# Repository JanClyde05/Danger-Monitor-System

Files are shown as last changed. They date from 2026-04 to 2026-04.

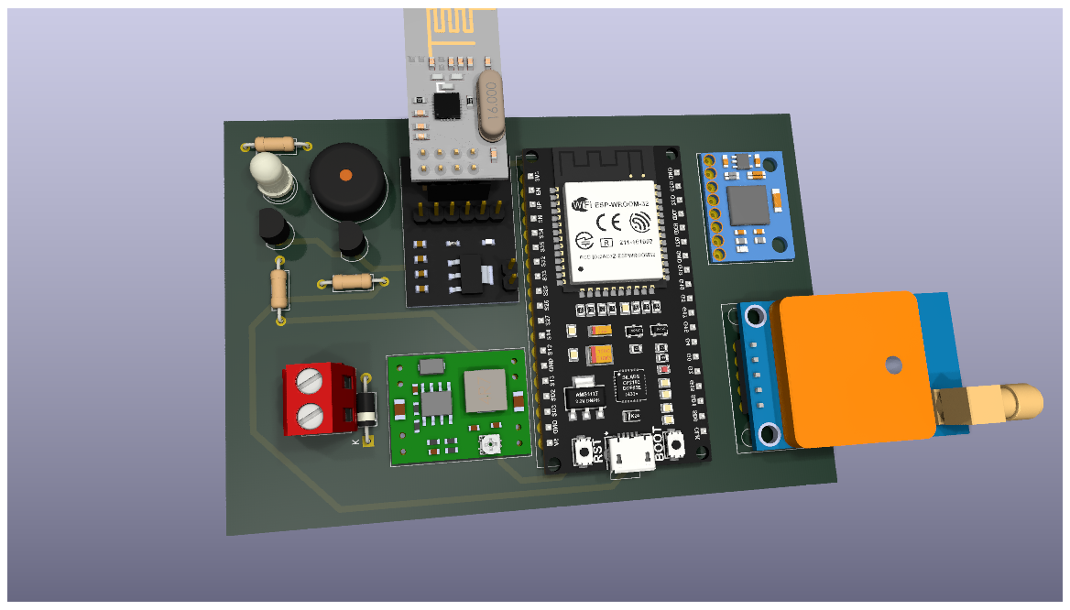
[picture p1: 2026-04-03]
images/Danger Monitor System 3D.png

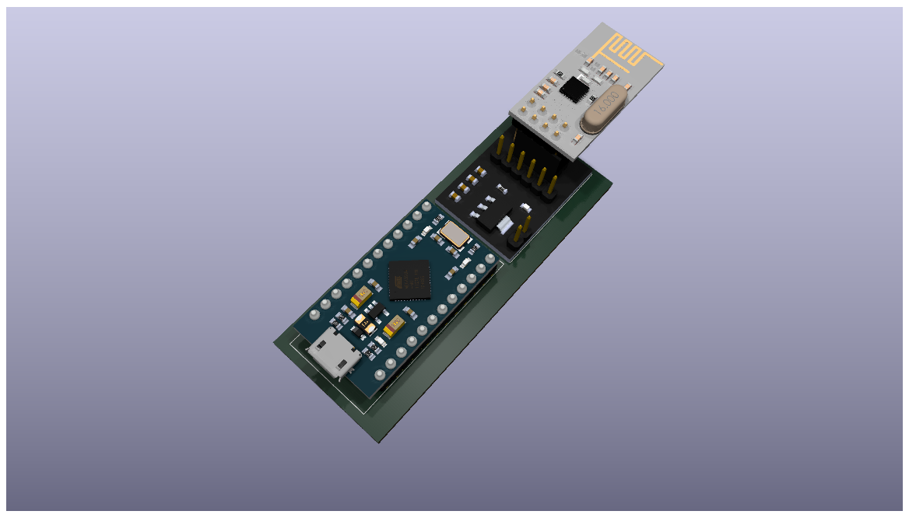
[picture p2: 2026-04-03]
images/Danger Monitor System_Receiver 3D.png

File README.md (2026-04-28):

# GPS Danger Monitor System – Full Code Documentation (v4.1)
##### BY: JAN CLYDE T. TALOSIG
##### **NEW IN v4.1: Physical Button Two-State Toggle + GPS Share / Open in Maps**
##### **NEW IN v4.0: Physical Disarm Button + False Alarm NRF Broadcast**
##### **NEW IN v3.x / Web Portal: Confirmed Accident Database + Diagnosis Notes + SOS Audio**

---

# 1. SYSTEM OVERVIEW

## 1.1 Purpose

The system is a **wearable/embedded safety monitor** that detects:

* Human falls (high confidence – three-stage FSM)
* Skid / slide events (lateral acceleration + roll rate)
* Direct high-G impacts (no freefall precondition)
* Environmental hazards (ground shock / structural instability / wave motion)

It then:

1. Gets GPS coordinates (last-known-location strategy)
2. Sends them via NRF24L01 with a token-prefixed payload
3. Triggers an SOS alert (LED + buzzer, Morse SOS pattern)
4. Opens a **web-based emergency profile with QR code quick-dial** via HID receiver
5. Allows the user to **cancel a false alarm** via physical button or web dashboard, which broadcasts a `FA,TOKEN,LAT,LNG` NRF packet to notify the receiver

---

## 1.2 System Components

### Transmitter (ESP32) – v4.1

* Sensors:
  * MPU-6050 (motion / orientation)
  * GPS module via TinyGPS++ (UART1, RX=16, TX=17)
* Communication:
  * NRF24L01 (wireless, CE=2, CSN=15)
* Interface:
  * Web dashboard in AP mode (three tabs: Monitor, Diagnostics, Simulation)
  * Physical disarm/re-arm button on GPIO 0 (BOOT button)

### Receiver (Pro Micro) – v2.3

* NRF24L01 (receiver, CE=9, CSN=10)
* HID Keyboard emulation (opens Netlify URL in browser)
* Handles three payload types: EMERGENCY, TEST, FALSE ALARM

### Web Layer

* ESP32 embedded dashboard (AP mode, 192.168.4.1)
* Netlify emergency portal (multi-page SPA with router)

---

# 2. ABSTRACT PROGRAM FLOW (SUMMARY)

## HIGH-LEVEL FLOW

```
BOOT → INIT HARDWARE → CALIBRATION → RUN LOOP
         ↓
     READ SENSORS (IMU + GPS)
         ↓
    APPLY SIM OVERRIDE (if drill mode)
         ↓
  UPDATE FALL-IMPACT-STILLNESS FSM
         ↓
  CHECK SKID / DIRECT IMPACT DETECTORS
         ↓
  CHECK ENVIRONMENTAL ANALYSIS (every 1 s)
         ↓
  SEND NRF ALERT + SOS (if triggered)
         ↓
  POLL PHYSICAL BUTTON (two-state toggle)
         ↓
  UPDATE WEB UI + BURST TEST (non-blocking)
         ↓
       REPEAT
```

---

## CORE LOGIC PIPELINES

### FALL DETECTION PIPELINE

```
[FS_IDLE]
   ↓ A_m < 0.40 g
[FS_FREEFALL]
   ↓ sustained ≥ 100 ms
[FS_WAIT_IMPACT]
   ↓ A_m > 3.00 g within 500 ms
[FS_STILLNESS]
   ↓ σ(A_m) < 0.15 g over 2 s
[FS_CONFIRMED → ALERT]
```

All stages must pass — eliminates false positives from jumping, device drops, or sleeping.

---

### SECONDARY DETECTORS (Parallel to FSM)

```
SKID / SLIDE:
  ay > 2.0 g  AND  gx > 330 °/s  sustained ≥ 200 ms
  → Ref: motorcycle crash paper, 96% accuracy

DIRECT IMPACT:
  A_m spike > 4.50 g  (no freefall precondition)
  5 s debounce between events
  → Ref: construction-site LF falls 4–9 g (Sensors 2022)
```

---

### EMERGENCY RESPONSE PIPELINE

```
[ACCIDENT DETECTED]
   ↓
[NRF PAYLOAD: "TOKEN,LAT,LNG"]
   ↓
[RECEIVER HID TRIGGERS URL]
   ↓
[NETLIFY PROFILE PAGE OPENS]
   ↓
[MEDICAL INFO + QR CODE DISPLAYED]
   ↓
[RESPONDER SCANS QR → tel: DIALS CONTACT]
   ↓ (optional)
[RESPONDER CONFIRMS ACCIDENT → DATABASE ENTRY]
```

---

### FALSE ALARM CANCELLATION PIPELINE (v4.0+)

```
[ALERT ACTIVE]
   ↓ (user presses physical button OR web False Alarm button)
[stopSOSAlert() — LED/buzzer off]
   ↓
[nrfSendFalseAlarm(): "FA,TOKEN,LAT,LNG"]
   ↓
[RECEIVER HID TRIGGERS FALSE ALARM URL]
   ↓
[NETLIFY: green "USER IS SAFE" page]
   ↓
[RESCUER INFORMED — NO RESPONSE NEEDED]
```

---

# 3. DETAILED MODULE EXPLANATION

## 3.1 SETUP PHASE

```
setup():
  Start Serial (115200)
  Start GPS UART1 (9600 baud, RX=16, TX=17)
  Initialize I2C (Wire.begin)
  Wake MPU-6050 (write 0x00 to PWR_MGMT_1)
  Calibrate MPU (3 seconds, 200 samples)
  Record gpsSearchStart timestamp
  Start WiFi AP (SSID: "GPS Danger Monitor", open, IP: 192.168.4.1)
  Initialize NRF24 (CE=2, CSN=15, PA_HIGH, 32-byte payload)
  Register all WebServer routes
  Configure GPIO: LED (4), Buzzer (5), Button (0 INPUT_PULLUP)
```

---

## 3.2 MAIN LOOP STRUCTURE

```
loop():
  Compute delta time dt
  server.handleClient()
  Poll physical button (50 ms debounce, two-state toggle)
  Run NRF burst test step (non-blocking, if pending)
  Feed GPS bytes → TinyGPS++, update hasFix / lastLat / lastLng
  readMPU() → apply sim override → updateOrientation(dt)
  Compute A_m = sqrt(ax²+ay²+az²)
  pushEnvSample(A_m, roll, pitch)
  Run Fall-Impact-Stillness FSM (if armed)
  Run Skid detector (if armed, FSM idle)
  Run Direct-Impact detector (if armed, FSM idle, not in skid)
  Environmental analysis (every 1 s, if armed, not sim)
  Drive SOS pattern (non-blocking)
```

---

# 4. SENSOR PROCESSING

## 4.1 MPU DATA FLOW

```
Raw MPU Data → Bias Removal → Physical Units → Orientation Estimation
```

### readMPU()

* Reads 14 bytes from register 0x3B
* Extracts ax, ay, az (±2 g range → /16384) and gx, gy, gz (±250 °/s → /131)
* Subtracts calibration offsets

### calibrateMPU()

* 200 samples over CALIB_MS (3000 ms)
* Averages each axis; subtracts 1.0 g from az bias (gravity)
* Stores: aBiasX/Y/Z, gBiasX/Y/Z

### updateOrientation(dt)

Complementary filter (α = 0.02):

```
aRoll  = atan2(ay, az) × 57.296°
aPitch = atan2(-ax, √(ay²+az²)) × 57.296°

roll  = (1-α)×(roll  + gx×dt) + α×aRoll
pitch = (1-α)×(pitch + gy×dt) + α×aPitch
```

## 4.2 ACCELERATION MAGNITUDE

```
A_m = sqrt(ax² + ay² + az²)
```

Orientation-independent scalar used by all detection stages.

---

# 5. FALL DETECTION STATE MACHINE

## States

| State | Meaning |
|---|---|
| FS_IDLE | Normal monitoring |
| FS_FREEFALL | Low-gravity condition detected |
| FS_WAIT_IMPACT  | Waiting for impact spike |
| FS_STILLNESS | Verifying post-impact unconscious |
| FS_CONFIRMED | Alert triggered |

## Full Flowchart

```
FS_IDLE
  IF A_m < 0.40 g → FS_FREEFALL, start timer

FS_FREEFALL
  IF A_m ≥ 0.40 g → back to FS_IDLE (false trigger)
  IF duration ≥ 100 ms → FS_WAIT_IMPACT
    Record fallStartMs, increment fallEventCount

FS_WAIT_IMPACT
  IF A_m > 3.00 g → FS_STILLNESS, reset stillness buffer
  IF timeout > 500 ms → FS_IDLE, increment fallCancelCount

FS_STILLNESS
  Collect samples for 2000 ms
  Compute σ(A_m)
  IF σ < 0.15 g → FS_CONFIRMED
  ELSE          → FS_IDLE (user conscious), increment fallCancelCount

FS_CONFIRMED
  Increment fallConfirmCount
  Log response time (now − fallStartMs)
  IF !simMode → nrfSendCoords(lastLat, lastLng, "Fall confirmed")
  ELSE        → nrfSendTest(99, "SIMFALL")
  startSOSAlert()
  → FS_IDLE
```

## Why This Works (Thesis Logic)

* Freefall alone → jumping false positive
* Impact alone → dropping the device
* Stillness alone → user sleeping
* **Combination of all three = confirmed real accident**

---

# 6. SECONDARY DETECTORS

## 6.1 Skid / Slide Detector

Active when: `armed == true` AND `fallState == FS_IDLE`

```
Condition: fabsf(ay) > 2.0 g  AND  fabsf(gx) > 330 °/s

If condition holds:
  Start skid timer on first detection
  If sustained ≥ 200 ms:
    skidCount++
    nrfSendCoords() OR nrfSendTest (sim)
    startSOSAlert()
    inSkid = false (reset)

If condition breaks before 200 ms:
  inSkid = false (cancel)
```

Reference: motorcycle crash paper, lateral 0.70 g + roll rate criteria, 96% accuracy.
*(Note: firmware thresholds are set higher — 2.0 g / 330 °/s — for reduced false positives in the specific deployment scenario.)*

---

## 6.2 Direct Impact Detector

Active when: `armed == true` AND `fallState == FS_IDLE` AND `!inSkid`

```
Condition: A_m > 4.50 g  AND  (now − lastImpactAlert) > 5000 ms

  lastImpactAlert = now
  impactCount++
  nrfSendCoords() OR nrfSendTest (sim)
  startSOSAlert()
```

Reference: Sensors 2022 — low-floor fall studies, 4–9 g impact range.

---

## 6.3 Environmental / Structural Instability

Runs every 1000 ms using the last `bufCount` samples from the rolling buffer (max 50).

```
sMag   = stddev(magBuf)
sRoll  = stddev(rollBuf)
sPitch = stddev(pitchBuf)

groundShock:  sMag ≥ 0.40  AND  sRoll < 10.0  AND  sPitch < 10.0
waveMotion:   sMag ≥ 0.24  AND  (sRoll ≥ 10.0 OR sPitch ≥ 10.0)

IF groundShock → nrfSendCoords("Ground shock")   + startSOSAlert()
IF waveMotion  → nrfSendCoords("Wave motion")     + startSOSAlert()
```

*(Environmental analysis is suppressed during simulation mode.)*

---

# 7. PHYSICAL BUTTON – TWO-STATE TOGGLE (v4.1)

**Pin:** GPIO 0 (BOOT button). Active-low with INPUT_PULLUP. 50 ms debounce on falling edge.

```
State A — alertActive = true:
  Press → armed = false
         stopSOSAlert()
         nrfSendFalseAlarm()   ← broadcasts "FA,TOKEN,LAT,LNG"
         lastEvent = "PHYSICAL DISARM – false alarm NRF sent/failed"

State B — armed = false (device was disarmed):
  Press → armed = true
         fallState = FS_IDLE
         inSkid = false
         lastEvent = "Re-armed via physical button"

Ignored — armed = true, alertActive = false:
  (Nothing to cancel — press is silently ignored)
```

---

# 8. NRF COMMUNICATION

## 8.1 Payload Formats (v4.1)

| Type | Format | Example |
|---|---|---|
| EMERGENCY | `TOKEN,LAT,LNG` | `DM-001,14.599512,120.984222` |
| FALSE ALARM | `FA,TOKEN,LAT,LNG` | `FA,DM-001,14.5995,120.9842` |
| TEST (burst/sim)| `TEST,NN,<tag>` | `TEST,01,SIMFALL` |

All payloads are 32 bytes (NRF_PAYLOAD). Lat/Lng precision is 6 decimal places for EMERGENCY, 4 decimal places for FALSE ALARM (to fit within the 32-byte limit alongside the `FA,` prefix and token).

**Known hardware constraint:** IMU readings (ax, ay, gx) are NOT included in the FALSE ALARM payload. The 32-byte capacity is fully occupied by token + GPS coordinates. The Netlify portal displays "—" for IMU fields on the false alarm page and explicitly notes this constraint.

---

## 8.2 NRF Send Functions

### nrfSendCoords(lat, lng, reason)
* Formats `TOKEN,LAT,LNG` into a 32-byte buffer
* Calls `radio.write()`
* Updates `lastEvent`

### nrfSendFalseAlarm()
* Formats `FA,TOKEN,LAT,LNG` (4-decimal precision)
* Calls `radio.write()`
* Returns bool success

### nrfSendTest(seq, tag)
* Formats `TEST,NN,<tag>` (used by burst test and simulation drills)
* Prevents real emergency alerts during drill mode

---

## 8.3 NRF Hardware Config

| Parameter | Value |
|---|---|
| CE Pin | GPIO 2 |
| CSN Pin | GPIO 15 |
| MOSI/MISO/SCK| 23 / 19 / 18 |
| Address | 0xE8E8F0F01LL |
| Payload size | 32 bytes |
| PA Level | RF24_PA_HIGH |
| Mode | TX (transmitter only)  |

---

# 9. WEB SERVER + DASHBOARD (ESP32)

## 9.1 Endpoints

| Route | Function |
|---|---|
| `/` | Serves full dashboard HTML (three tabs) |
| `/status.json` | Live sensor data (armed, alertActive, GPS, IMU, fall state, sim) |
| `/diag-stats.json` | GPS fix stats, fall event counters, burst state |
| `/burst-results.json`  | 20-shot burst test results per packet |
| `/arm` | Set armed = true |
| `/disarm` | Set armed = false, stop SOS; if alertActive → send FA NRF |
| `/false-alarm` | Manual FA: only works when alertActive; sends FA NRF  |
| `/test-nrf` | Single legacy NRF test packet |
| `/run-burst` | Start 20-packet burst test (non-blocking) |
| `/simulate?event=X` | Start simulation (skid / fall / impact) |
| `/sim-stop` | Stop simulation, reset IMU to idle state |

## 9.2 /status.json Fields

```json
{
  "armed":       true,
  "alertActive": false,
  "hasFix":      true,
  "lat":         14.599512,
  "lng":         120.984222,
  "roll":        2.30,
  "pitch":      -1.20,
  "aMag":        1.023,
  "ay":          0.012,
  "gx":          0.5,
  "nrfReady":    true,
  "fallState":   0,
  "simEvent":    0,
  "inSkid":      false,
  "lastEvent":   "System boot"
}
```

## 9.3 Dashboard Tabs

### Monitor Tab
* **Alert Active Banner** — animated red banner shown when `alertActive = true`; includes hint about physical button and False Alarm button
* **System Controls** — Arm, Disarm, False Alarm (disabled when no active alert), NRF Single Test
* **Live Sensor Data** — 11 KV tiles: Armed, Alert Active, GPS Fix, Lat, Lng, Roll, Pitch, |A|, A-Y lateral, GX roll rate, NRF24 status
* **Fall Pipeline Bar** — color-coded progress bar across 5 FSM stages
* **GPS Location Actions** (v4.1 new):
  * **Share Location** button — copies `https://www.google.com/maps?q=LAT,LNG` to clipboard; disabled until valid GPS fix
  * **Open in Maps** button — opens Google Maps pin in new browser tab; disabled until valid GPS fix
  * GPS coordinate display below buttons (green when fix acquired)
* **Last Event** — monospace event log display
* **Detection Thresholds Reference** — literature-backed threshold summary with physical button behavior note

### Diagnostics Tab
* **NRF Burst Test** — 20-shot burst with per-packet ACK/FAIL status, latency bar, summary stats (success rate, avg/min/max delay)
* **GPS Fix Statistics** — fix count, average time-to-fix, current fix status
* **Fall Detection Diagnostics** — events detected, confirmed alerts, cancelled events, avg response time, precision rate, skid count, direct impact count

### Simulation Tab
* **Event Buttons** — Simulate Skid (SIM_SKID), Simulate Fall (SIM_FALL), Simulate Impact (SIM_IMPACT), Stop Sim
* **Sim Status Display** — live status string from `lastEvent`
* **IMU Threshold Reference Table** — literature-backed thresholds with event name, value, condition, and source
* **Live IMU Waveform Canvas** — rolling 80-sample aMag plot with threshold lines (freefall 0.40 g, skid 0.70 g, impact 3.00 g, direct 4.00 g)

---

# 10. IMU SIMULATION MODE

Three simulation events inject synthetic IMU waveforms to test the detection pipeline end-to-end without physically triggering the device.

### SIM_SKID (~700 ms)
* Sine-enveloped lateral ay peak ~0.85 g + gx peak ~55 °/s
* Designed to cross SKID_LATERAL_G and SKID_ROLL_RATE thresholds
* Sends `nrfSendTest(98, "SIMSKID")` instead of real alert

### SIM_FALL (~2650 ms)
```
0–100 ms  : Pre-fall lean (az drops, gx rises)
100–280 ms: Freefall (A_m ≈ 0.18 g — well below 0.40 g threshold)
280–330 ms: Impact spike (A_m ≈ 4.8 g — above 3.00 g threshold)
330–2650 ms: Stillness (σ < 0.05 g — below 0.15 g threshold)
```
* Sends `nrfSendTest(99, "SIMFALL")`

### SIM_IMPACT (~200 ms)
* Gaussian impulse: peak A_m ≈ 4.8 g (above IMPACT_DIRECT_G = 4.50 g)
* Sends `nrfSendTest(97, "SIMIMPACT")`

All simulations set `lastEvent` with drill status and suppress real NRF emergency packets.

---

# 11. RECEIVER (PRO MICRO) – v2.3

## 11.1 Three Payload Types

```
WAIT for NRF packet (radio.available())
   ↓
Read 32-byte payload → String raw
   ↓
Detect type:
  raw.startsWith("TEST,")  → TEST handler
  raw.startsWith("FA,")    → FALSE ALARM handler
  else                     → EMERGENCY handler
```

## 11.2 EMERGENCY Handler

```
Parse: TOKEN = raw[0..c1], COORDS = raw[c1+1..]
Build URL: https://danger-monitor-profile.netlify.app/?token=TOKEN&loc=LAT,LNG
Debounce: 1500 ms between triggers
openURL(url) → HID keyboard simulation
```

## 11.3 FALSE ALARM Handler (v2.3 New)

```
Parse: FA | TOKEN | LAT | LNG
Build URL: https://danger-monitor-profile.netlify.app/?falarm=1&token=TOKEN&loc=LAT,LNG
Debounce: 1500 ms
openURL(url) → HID keyboard simulation
```
→ Netlify displays **green "USER IS SAFE" page** instead of emergency profile.

## 11.4 TEST Handler

```
Parse seq number from "TEST,NN,tag"
Build URL: https://danger-monitor-profile.netlify.app/?nrftest=1&seq=NN&ts=millis
Debounce: 1500 ms
openURL(url)
```
→ Netlify shows a toast notification and stays on home page.

## 11.5 openURL() – HID Sequence

```
Keyboard.press(Ctrl + L)   → focus address bar
Keyboard.releaseAll()
delay(250)
Keyboard.press(Ctrl + A)   → select existing URL
Keyboard.releaseAll()
delay(80)
Keyboard.print(url)        → type new URL
delay(80)
Keyboard.write(KEY_RETURN) → navigate
```

## 11.6 Wiring

| NRF24 Pin | Pro Micro Pin |
|---|---|
| CE | 9 |
| CSN | 10 |
| MOSI | 16 (MOSI) |
| MISO | 14 (MISO) |
| SCK | 15 (SCK) |
| VCC | 3.3 V only |

---

# 12. NETLIFY EMERGENCY PORTAL (Web Layer)

## 12.1 Technology Stack

```
HTML5 / CSS3 / Vanilla JavaScript
QRCode.js (CDN: cdnjs.cloudflare.com)
localStorage (Confirmed Accident Database)
Web Audio API (SOS sound engine)
No backend required — fully static
```

## 12.2 URL Router

The portal reads URL parameters on load and routes to the correct page:

| URL Pattern | Page Shown |
|---|---|
| `/` (no params) | Home – Device Grid |
| `/?token=DM-001&loc=14.599,120.984` | Emergency Profile |
| `/?falarm=1&token=DM-001&loc=14.5995,120.9842` | False Alarm – Safe Page |
| `/?nrftest=1&seq=NN&ts=...` | Home + toast |
| `/?loc=14.599,120.984` (no token) | First profile (legacy)  |
| `/?token=DM-XXX` (unknown token) | Token Not Found page |

## 12.3 Pages

### Home Page
* Hero section: system description, stats (device count, repeater spacing, RF protocol)
* **Device Grid** — card per profile showing avatar, name, role, token, blood type, contact
* Clicking any card opens that profile's Emergency Profile view

### Emergency Profile Page
* **Alert Banner** — animated red pulsing banner with SOS mute toggle button
* **Audio Unlock Bar** — shown on mobile when autoplay is blocked; tap to enable SOS alarm
* **Medical Profile Card** — avatar, name, role, token, blood type, allergies, emergency contact, medical notes
* **QR Code Section** — auto-generated `tel:` QR code for instant emergency contact dial
* **Location Card** — live coordinates, Google Maps button (hidden if no location)
* **Rescuer Action Row**:
  * **Share Alert** — copies current emergency URL to clipboard
  * **Confirm Accident** — opens token-confirmation modal; logs entry to Confirmed Accident Database
* Back button → Home

### False Alarm Page
* **Safe Banner** — green pulsing "USER IS SAFE" banner
* **Safe Status Row** — green indicator dot + "DEVICE OWNER CONFIRMED SAFE" text
* **Profile Card (green border)** — same medical info as emergency profile
* **IMU Readings at Disarm** — displays "—" for all three fields with hardware constraint note
* **Location Card** — last-known GPS position

### Confirmed Accident Database Page
* Header with record count and Clear All button
* Per-entry cards showing: avatar, name, token, confirmed timestamp, coordinates (Maps link), medical summary
* **Medical Diagnosis Notes** — collapsible section per accident:
  * Add Text Note (textarea)
  * Add Image (file input → base64)
  * Attach File (file input → base64 data URL)
  * Delete individual notes
* **Delete Accident Record** — per-card ✕ button; requires token confirmation via modal
* Empty state placeholder when no records

### Token Not Found Page
* Shows the unrecognized token string
* Back button → Home

## 12.4 Token Confirmation Modal

Used for both "Confirm Accident" and "Delete Record" actions.

```
openModal({
  mode:  'confirm' | 'delete',
  token: required token string,
  onOk:  callback on success
})
```

* User must type the device token exactly (case-insensitive) to unlock the OK button
* Input highlights green on match; button label differs by mode ("Log to Database" vs "Delete")
* Dismiss via Cancel button, backdrop click, or Escape key

## 12.5 QR Code System

```javascript
generateQRCode(phoneNumber, containerId)
  telLink = 'tel:' + phoneNumber.replace(/\s/g, '')
  new QRCode(container, {
    text:         telLink,
    width:        200, height: 200,
    colorDark:    '#000000',
    colorLight:   '#ffffff',
    correctLevel: QRCode.CorrectLevel.H   // 30% error recovery
  })
```

| Property | Value |
|---|---|
| Encoding | `tel:` URI protocol |
| Size | 200 × 200 px |
| Error Correction| Level H (30% recovery) |
| Generation | Client-side (instant)  |
| Offline support | Yes (no network needed)|

## 12.6 SOS Audio Engine

Non-blocking Morse SOS pattern using Web Audio API:

```
Pattern: ... --- ...  (dot=80ms, dash=240ms, gap=80ms, long gap=240ms, word gap=560ms)
Tone:    880 Hz sine wave, gain 0.35
```

* `SOS.tryAutoplay()` — called on profile load; shows unlock bar if browser blocks autoplay
* `SOS.start()` / `SOS.stop()` — start/stop the oscillator pattern loop
* `SOS.toggleMute()` — mute/unmute without stopping the pattern timer
* SOS is always stopped when navigating to False Alarm page or Home

## 12.7 Confirmed Accident Database (localStorage)

```
Key: 'dm_accidents'
Schema per entry:
{
  id:          string (timestamp),
  confirmedAt: ISO date string,
  token:       "DM-XXX",
  profile:     { ...snapshot of profile at time of confirmation },
  loc:         "LAT,LNG" or "",
  url:         full emergency URL,
  diagNotes:   [
    {
      id:       string,
      addedAt:  ISO date string,
      type:     "text" | "image" | "file",
      content:  text string | base64 data URL,
      fileName: string,
      mimeType: string
    }
  ]
}
```

Entries are stored newest-first. Image and file notes are stored as base64 data URLs. A 2 MB per-file warning prompt is shown to prevent exceeding localStorage limits (~5–10 MB per origin).

## 12.8 Registered Profiles

```javascript
const PROFILES = [
  { token: "DM-001", name: "Jan Clyde Talosig",     blood: "B+",  allergies: "None",          ... },
  { token: "DM-002", name: "James Laurence Guzman", blood: "O+",  allergies: "Skin Allergies", ... },
  { token: "DM-003", name: "Kaye Angelique Aquino", blood: "A+",  allergies: "None",           ... },
  { token: "DM-004", name: "Shamel Alliyah Senson", blood: "AB+", allergies: "None",           ... },
  { token: "DM-005", name: "Zarina Marie Aguilar",  blood: "AB+", allergies: "None",
    notes: "Have history of heart complications"                                                  },
];
```

To add a new device, append a new object to the `PROFILES` array in `emergency_portal_qr.html`.

---

# 13. SOS ALERT SYSTEM

## Pattern

Morse Code SOS: `... --- ...` (non-blocking)

```javascript
const SOS_STEPS = [
  {on:true,ms:150},{on:false,ms:150},  // S dot 1
  {on:true,ms:150},{on:false,ms:150},  // S dot 2
  {on:true,ms:150},{on:false,ms:150},  // S dot 3
  {on:true,ms:450},{on:false,ms:150},  // O dash 1
  {on:true,ms:450},{on:false,ms:150},  // O dash 2
  {on:true,ms:450},{on:false,ms:150},  // O dash 3
  {on:true,ms:150},{on:false,ms:150},  // S dot 1
  {on:true,ms:150},{on:false,ms:150},  // S dot 2
  {on:true,ms:150},{on:false,ms:600},  // S dot 3 + word gap
];
```

* LED (GPIO 4) and Buzzer (GPIO 5, 3000 Hz) toggled in sync
* `startSOSAlert()` — sets `alertActive = true`, starts pattern
* `stopSOSAlert()` — sets `alertActive = false`, turns off LED and buzzer
* Pattern cycles with `millis()` timing — does not block the main loop

---

# 14. GPS HANDLING

## Strategy: Last-Known Location

```
IF GPS valid:
    update lastLat, lastLng
    IF first fix after search: record fix time, increment gpsFixCount
ELSE:
    keep last valid coordinates (lastLat, lastLng)

IF fix age > 8000 ms:
    hasFix = false → start searching
```

## GPS Diagnostics

Tracked in firmware and exposed via `/diag-stats.json`:
* `gpsFixCount` — number of times a fix was (re-)acquired
* `gpsTotalFixMs` — cumulative time-to-fix; divide by count for average
* `gpsSearchStart` — timestamp of last fix-lost event

---

# 15. SYSTEM STATES

## Armed Mode (`armed = true`)

* All detection FSMs active (fall, skid, direct impact, environmental)
* SOS alerts allowed
* NRF broadcasting enabled
* Physical button in State A/Ignored logic

## Disarmed Mode (`armed = false`)

* All FSMs reset to idle
* SOS stopped
* NRF dormant
* Physical button in State B (re-arm) logic

## Alert Active (`alertActive = true`)

* Subset of armed mode — a confirmed event is in progress
* SOS LED/buzzer cycling
* Web dashboard shows animated red banner
* False Alarm button enabled
* Physical button triggers disarm + FA NRF

---

# 16. KEY VARIABLES YOU CAN MODIFY

## Detection Thresholds

```cpp
// Fall-Impact-Stillness
FREEFALL_G        = 0.40f    // g — below this triggers freefall
IMPACT_G          = 3.00f    // g — above this after freefall = impact
STILLNESS_STD_MAX = 0.15f    // g σ — below this = unconscious
FREEFALL_DUR_MS   = 100      // ms — min freefall duration
IMPACT_WINDOW_MS  = 500      // ms — impact must occur within this window
STILLNESS_DUR_MS  = 2000     // ms — stillness observation window

// Skid
SKID_LATERAL_G    = 2.0f     // g — lateral ay threshold
SKID_ROLL_RATE    = 330.0f   // °/s — gx roll rate threshold
SKID_DUR_MS       = 200      // ms — sustained duration

// Direct Impact
IMPACT_DIRECT_G   = 4.50f    // g — spike threshold
IMPACT_DEBOUNCE   = 5000     // ms — minimum time between direct impact alerts

// Environmental
ACC_STD_DANGER    = 0.40f    // g σ — acceleration variance threshold
ROLL_PITCH_STD    = 10.0f    // ° σ — orientation variance threshold
ANALYZE_EVERY_MS  = 1000     // ms — analysis interval
```

## Hardware Pins

```cpp
GPS_RX = 16, GPS_TX = 17, GPS_BAUD = 9600
MPU_ADDR = 0x68 (I2C, SDA=21, SCL=22)
NRF_CE = 2, NRF_CSN = 15
ALERT_LED_PIN = 4
BUZZER_PIN = 5
DISARM_BTN_PIN = 0
```

## Device Token

```cpp
const char* DEVICE_TOKEN = "DM-001";
```

Each physical device must have a unique token matching an entry in the `PROFILES` array.

---

# 17. FULL SYSTEM ARCHITECTURE

## v4.1 Block Diagram

```
[MPU6050] ──┐
            ├─→ ESP32 ─→ FALL / SKID / IMPACT FSMs ─→ NRF24 ──┐
[GPS]    ───┘      ↓              ↓                            │
                SOS ALERT   Physical BTN (GPIO 0)              │
               (LED/Buzz)    ↓ (if alertActive)                │
                         FA NRF packet ──────────────────────  │
                                                               ↓
                                                          Pro Micro
                                                               ↓
                                                 HID Keyboard Emulation
                                                               ↓
                                              Browser → Netlify Portal
                                                               ↓
                                         ┌──────────────────────────────┐
                                         │  Emergency Profile + QR      │
                                         │  OR False Alarm Safe Page    │
                                         │  OR Test Toast Notification  │
                                         └──────────────────────────────┘
                                                               ↓
                                                  Responder Scans QR
                                                               ↓
                                                   Phone Auto-Dials
                                                               ↓
                                           (optional) Confirm Accident
                                                               ↓
                                              Accident Database Entry
                                                               ↓
                                          Medical Personnel Adds Notes
```

---

## Data Flow – Emergency Scenario

```
TRANSMITTER (ESP32):
  Fall / Skid / Impact Detected
       ↓
  GPS: lastLat, lastLng
       ↓
  Payload: "DM-001,14.599512,120.984222"
       ↓
  NRF24 → radio.write()
       ↓
  SOS LED + Buzzer activated

RECEIVER (Pro Micro):
  radio.available() → radio.read()
       ↓
  Payload type: EMERGENCY (no "FA," prefix, no "TEST," prefix)
       ↓
  Parse: token="DM-001", coords="14.599512,120.984222"
       ↓
  URL: https://danger-monitor-profile.netlify.app/?token=DM-001&loc=14.599512,120.984222
       ↓
  HID: Ctrl+L → Ctrl+A → type URL → Enter

NETLIFY PORTAL:
  route() reads params
       ↓
  PROFILES.find(token === "DM-001")
       ↓
  renderProfile(profile, "14.599512,120.984222")
       ↓
  Display: photo, name, blood type, allergies, contact, notes
  Generate: QR code (tel:+63917XXXXXX)
  Show:     Google Maps link
  Play:     SOS audio (880 Hz Morse pattern)
       ↓
  Responder scans QR → phone dials contact
  (optional) Rescuer clicks "Confirm Accident" → enters token → logs to DB
```

---

## Data Flow – False Alarm Scenario

```
TRANSMITTER (ESP32):
  User presses GPIO 0 while alertActive = true
       ↓
  stopSOSAlert() — LED/buzzer off
       ↓
  nrfSendFalseAlarm()
  Payload: "FA,DM-001,14.5995,120.9842"
       ↓
  armed = false

RECEIVER (Pro Micro):
  raw.startsWith("FA,") → FALSE ALARM handler
       ↓
  Parse: token="DM-001", loc="14.5995,120.9842"
       ↓
  URL: https://danger-monitor-profile.netlify.app/?falarm=1&token=DM-001&loc=14.5995,120.9842
       ↓
  HID: openURL()

NETLIFY PORTAL:
  route() detects falarm=1
       ↓
  renderFalseAlarm(profile, loc)
       ↓
  Green "USER IS SAFE" banner + profile info
  SOS audio stopped
  IMU fields show "—" (hardware constraint)
  Last known GPS position displayed
```

---

# 18. DEPLOYMENT CHECKLIST (v4.1)

## Transmitter Setup

- [ ] Program ESP32 with v4.1 firmware
- [ ] Set `DEVICE_TOKEN` to match Netlify `PROFILES` entry (e.g., `"DM-001"`)
- [ ] Configure WiFi AP SSID/password in `AP_SSID` / `AP_PASS`
- [ ] Set NRF24 channel and address to match receiver
- [ ] Calibrate MPU-6050 (hold device still during 3 s boot calibration)
- [ ] Test GPS fix (outdoor location, wait for `hasFix = true`)
- [ ] Verify SOS alert (LED + buzzer)
- [ ] Test physical button: arm → trigger alert → press button → verify FA NRF + disarm → press again → verify re-arm

## Receiver Setup

- [ ] Program Pro Micro with v2.3 firmware
- [ ] Configure NRF24 CE=9, CSN=10 to match transmitter address
- [ ] Test NRF pairing (LED blink on packet reception)
- [ ] Connect to PC via USB (HID driver auto-installs)
- [ ] Test keyboard emulation with a test payload

## Web Portal Setup

- [ ] Update `PROFILES` array with real names, photos, and contact numbers
- [ ] Deploy `emergency_portal_qr.html` to Netlify
- [ ] Test emergency URL: `?token=DM-001&loc=14.599,120.984`
- [ ] Test false alarm URL: `?falarm=1&token=DM-001&loc=14.5995,120.9842`
- [ ] Test NRF test URL: `?nrftest=1&seq=01&ts=12345`
- [ ] Verify QR code generation and mobile scan-to-dial
- [ ] Test Confirm Accident flow → Database entry → Diagnosis notes
- [ ] Test Delete Record flow with token confirmation
- [ ] Verify SOS audio on mobile (tap unlock bar if needed)

## Field Testing

- [ ] Controlled fall drill: use Simulate Fall on dashboard, verify FSM progression
- [ ] Skid drill: use Simulate Skid, verify NRF test packet sent
- [ ] Impact drill: use Simulate Impact, verify direct-impact alert
- [ ] Physical button false alarm test (step-by-step toggle)
- [ ] Web disarm false alarm test (dashboard button)
- [ ] NRF 20-shot burst test (check success rate ≥ 90%)
- [ ] GPS Share Location — copy link, verify coordinates
- [ ] GPS Open in Maps — verify correct pin location
- [ ] End-to-end: fall → NRF → browser opens profile → QR scan → call

---

# 19. VERSION COMPARISON

| Feature | v2.1 | v4.0 | v4.1 |
|---|---|---|---|
| Fall detection | FSM (3-stage)| FSM (3-stage) | FSM (3-stage) |
| Skid detection | ✗ | ✓ | ✓ |
| Direct impact detection | ✗ | ✓ | ✓ |
| Simulation drills | ✗ | ✓ | ✓ |
| NRF burst test | ✗ | ✓ | ✓ |
| Physical disarm button | ✗ | Single-press | Two-state toggle |
| Physical re-arm | ✗ | ✗ | ✓ (second press) |
| False alarm NRF packet | ✗ | ✓ | ✓ |
| False alarm Netlify page | ✗ | ✗ | ✓ (green safe page) |
| GPS Share Location button | ✗ | ✗ | ✓ |
| GPS Open in Maps button | ✗ | ✗ | ✓ |
| Multi-profile support | Token-based | Token-based | Token-based (5 profiles)|
| QR code quick-dial | ✓ | ✓ | ✓ |
| Confirmed accident database | ✗ | ✗ | ✓ (localStorage) |
| Medical diagnosis notes | ✗ | ✗ | ✓ (text/image/file) |
| SOS audio (browser) | ✗ | ✗ | ✓ (Web Audio API) |
| Alert Active indicator | ✗ | ✓ | ✓ |
| Dashboard tabs | 1 | 3 | 3 |
| Receiver payload types | 1 | 2 | 3 (EM + TEST + FA) |

---

# 20. FINAL NOTES (v4.1)

✔ Non-blocking design throughout (SOS, burst test, button debounce, GPS feed)
✔ Multi-layer detection: Fall FSM + Skid + Direct Impact + Environmental
✔ Two-state physical button toggle: disarm+FA when alert active, re-arm when disarmed
✔ GPS Share and Open in Maps for rapid responder location relay
✔ Token-based routing with 5 registered device profiles
✔ Zero-installation responder workflow (browser-based Netlify portal)
✔ False alarm broadcast prevents unnecessary emergency response
✔ Confirmed accident database with full medical diagnosis notes system
✔ SOS audio engine with mobile autoplay unlock handling
✔ IMU simulation drills with realistic waveforms for pre-deployment testing
✔ Thesis-grade documentation with literature-backed detection thresholds

---

**Last Updated:** April 2026
**Firmware Versions:** ESP32 v4.1 | Pro Micro Receiver v2.3 | Netlify Portal v4.x
**Status:** Production Ready

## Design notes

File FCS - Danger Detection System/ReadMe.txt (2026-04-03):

# GPS Danger Monitor System – Full Code Documentation (v2.0)

---

# 1. SYSTEM OVERVIEW

## 1.1 Purpose

The system is a **wearable/embedded safety monitor** that detects:

* Human falls (high confidence)
* Environmental hazards (ground shock / instability)

It then:

1. Gets GPS coordinates
2. Sends them via NRF24L01
3. Triggers an SOS alert (LED + buzzer)
4. Opens a web-based emergency profile via HID receiver

---

## 1.2 System Components

### Transmitter (ESP32)

* Sensors:

  * MPU-6050 (motion)
  * GPS (TinyGPS++)
* Communication:

  * NRF24L01 (wireless)
* Interface:

  * Web dashboard (AP mode)

### Receiver (Pro Micro)

* NRF24L01 (receiver)
* HID Keyboard (opens alert URL)

### Web Layer

* Embedded dashboard (ESP32)
* Netlify emergency profile page

---

# 2. ABSTRACT PROGRAM FLOW (SUMMARY)

## HIGH-LEVEL FLOW

```
BOOT → INIT HARDWARE → CALIBRATION → RUN LOOP
         ↓
     READ SENSORS
         ↓
  UPDATE STATE MACHINE
         ↓
  CHECK ENVIRONMENTAL EVENTS
         ↓
  SEND ALERT (NRF + SOS)
         ↓
  UPDATE WEB UI
         ↓
       REPEAT
```

---

## CORE LOGIC PIPELINE

### FALL DETECTION PIPELINE

```
[IDLE]
   ↓ (A_m < 0.4g for 100ms)
[FREEFALL]
   ↓ (A_m > 3g within 500ms)
[IMPACT]
   ↓ (low motion for 2s)
[STILLNESS]
   ↓
[CONFIRMED FALL → ALERT]
```

✔ ALL stages must pass → eliminates false positives

---

# 3. DETAILED MODULE EXPLANATION

---

# 3.1 SETUP PHASE

## Responsibilities

* Initialize all hardware
* Configure communication
* Calibrate sensors

## Steps

```
setup():
  Start Serial
  Start GPS UART
  Initialize I2C (MPU)
  Wake MPU
  Calibrate MPU (3 seconds)
  Start WiFi AP
  Initialize NRF24
  Setup WebServer routes
  Configure GPIO (LED, buzzer)
```

---

# 3.2 MAIN LOOP EXECUTION

## Loop Cycle Structure

```
loop():
  Compute delta time (dt)
  Handle web requests
  Read GPS
  Read IMU
  Compute acceleration magnitude
  Run fall detection FSM
  Run environmental analysis
  Update SOS alert pattern
```

---

# 4. SENSOR PROCESSING

---

## 4.1 MPU DATA FLOW

```
Raw MPU Data → Bias Removal → Physical Units → Orientation Estimation
```

### Functions

#### readMPU()

* Reads 14 bytes from MPU
* Extracts:

  * Acceleration (ax, ay, az)
  * Gyroscope (gx, gy, gz)
* Applies calibration offsets

---

#### calibrateMPU()

* Collects ~200 samples
* Computes average bias
* Adjusts:

  * accel offset
  * gyro drift

---

#### updateOrientation(dt)

* Uses complementary filter:

  * Gyro = fast response
  * Accel = stable reference

```
roll = (1-α)*gyro + α*accel
pitch = (1-α)*gyro + α*accel
```

---

## 4.2 ACCELERATION MAGNITUDE

```
A_m = sqrt(ax² + ay² + az²)
```

✔ Orientation-independent
✔ Used for fall detection

---

# 5. FALL DETECTION STATE MACHINE (CRITICAL)

---

## States

| State | Meaning |
| --- | --- |
| FS_IDLE | Monitoring |
| FS_FREEFALL | Low gravity detected |
| FS_WAIT_IMPACT | Waiting for spike |
| FS_STILLNESS | Checking unconsciousness |
| FS_CONFIRMED | Alert triggered |

---

## FULL FLOWCHART (DETAILED)

```
START (FS_IDLE)

IF A_m < 0.4g:
    → FS_FREEFALL
    → Start timer

FS_FREEFALL:
    IF A_m rises early:
        → FALSE TRIGGER → FS_IDLE
    IF duration ≥100ms:
        → FS_WAIT_IMPACT

FS_WAIT_IMPACT:
    IF A_m > 3g:
        → IMPACT DETECTED
        → FS_STILLNESS
    IF timeout >500ms:
        → CANCEL → FS_IDLE

FS_STILLNESS:
    Collect samples for 2 seconds

    Compute standard deviation σ

    IF σ < 0.15:
        → USER NOT MOVING
        → FS_CONFIRMED
    ELSE:
        → USER MOVING → SAFE
        → FS_IDLE

FS_CONFIRMED:
    Send NRF alert
    Activate SOS
    Return to FS_IDLE
```

---

## WHY THIS WORKS (THESIS LOGIC)

* Freefall alone → jumping false positive
* Impact alone → dropping device
* Stillness alone → sleeping

✔ COMBINATION = real accident detection

---

# 6. ENVIRONMENTAL ANALYSIS

---

## Purpose

Detect:

* Structural impacts
* Unstable movement (waves, tumbling)

---

## Method

### Rolling Buffer

* Stores last 50 samples:

  * acceleration magnitude
  * roll
  * pitch

---

## Standard Deviation Calculation

```
σ = sqrt( (Σx²/n) − (Σx/n)² )
```

---

## Detection Logic

### Ground Shock

```
High accel variance
LOW orientation change
```

→ Indicates sudden impact (e.g., drop)

---

### Wave Motion

```
Moderate accel variance
HIGH orientation variation
```

→ Indicates instability

---

## Actions

```
IF groundShock OR waveMotion:
    Send NRF
    Trigger SOS
```

---

# 7. NRF COMMUNICATION

---

## Payload Format

```
"LAT,LNG"
Example:
"14.599512,120.984222"
```

---

## Transmission Flow

```
ESP32:
  Format string
  radio.write()

Receiver:
  radio.read()
  Parse coordinates
  Trigger HID keyboard
```

---

# 8. RECEIVER (PRO MICRO) FLOW

---

## Logic

```
WAIT for NRF data
   ↓
Read payload
   ↓
Validate format
   ↓
Construct URL:
https://danger-monitor-profile.netlify.app/?loc=LAT,LNG
   ↓
Simulate keyboard:
  Ctrl+L
  Ctrl+A
  Type URL
  Press Enter
```

---

## Result

Browser automatically opens emergency page

---

# 9. SOS ALERT SYSTEM

---

## Pattern

Morse Code: SOS

```
... --- ...
```

### Implementation

* Non-blocking timing
* Array of ON/OFF durations

---

## Logic

```
startSOSAlert():
  Initialize pattern index
  Set first state

loop():
  If time reached:
    Move to next step
    Toggle LED + buzzer
```

---

# 10. WEB SERVER + UI

---

## Endpoints

| Route | Function |
| --- | --- |
| / | Dashboard UI |
| /status.json | System data |
| /arm | Enable detection  |
| /disarm | Disable detection |
| /test-nrf | Manual test |

---

## Data JSON Example

```
{
  "armed": true,
  "lat": 14.599,
  "lng": 120.984,
  "roll": 2.3,
  "pitch": -1.2,
  "aMag": 1.02,
  "fallState": 2
}
```

---

## UI Behavior

* Refresh every ~900 ms
* Displays:

  * GPS
  * motion
  * system status
  * fall pipeline progress

---

# 11. GPS HANDLING

---

## Strategy: Last-Known Location

```
IF GPS valid:
    update coordinates
ELSE:
    keep last valid position
```

✔ Ensures location is always available
✔ Works in GPS dead zones

---

# 12. SYSTEM STATES

---

## Armed Mode

* All detections active
* Alerts allowed

## Disarmed Mode

* FSM disabled
* Alerts stopped

---

# 13. KEY VARIABLES YOU CAN MODIFY

---

## Detection Sensitivity

```
FREEFALL_G        (default 0.40g)
IMPACT_G          (default 3.0g)
STILLNESS_STD_MAX (default 0.15g)
```

---

## Timing

```
FREEFALL_DUR_MS
IMPACT_WINDOW_MS
STILLNESS_DUR_MS
```

---

## Environmental Detection

```
ACC_STD_DANGER
ROLL_PITCH_STD
```

---

# 14. HOW TO MODIFY SYSTEM BEHAVIOR

---

## Change Detection Logic

Edit:

```
switch(fallState)
```

---

## Change Alert Behavior

Edit:

```
startSOSAlert()
SOS_STEPS[]
```

---

## Change Communication

Edit:

```
nrfSendCoords()
```

---

## Change UI

Edit:

```
web_ui.h
```

---

## Change Receiver Behavior

Edit:

```
Keyboard.print()
```

---

# 15. FULL SYSTEM ARCHITECTURE

```
[MPU6050] ──┐
            ├─→ ESP32 → FALL DETECTION → NRF24 → Pro Micro → Browser
[GPS]    ───┘                        ↓
                                SOS ALERT
                                ↓
                          Web Dashboard (AP)
```

---

# 16. FINAL NOTES

✔ Non-blocking design
✔ Multi-layer detection (robust)
✔ Modular architecture (easy to expand)
✔ Thesis-ready logic (high reliability)

---

# END OF DOCUMENT

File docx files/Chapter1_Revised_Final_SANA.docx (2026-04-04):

Road Accident Prevention in High-Risk Areas Using an IoT-Based GPS Danger Monitoring System with Real-Time Alert Capabilities

AGUILAR, ZARINA MARIE

AQUINO, KAYE ANGELIQUE

BAQUIRAN, MIA CARLA

GUZMAN, JAMES LAWRENCE

RAMOS, AYESSA MARIE

REQUIMIN, KATHLEEN

SENSON, SHAMEL ALLIYAH

Lead: TALOSIG, JAN CLYDE

SUBMITTED TO THE FACULTY OF THE

DEPARTMENT OF ELECTRONICS ENGINEERING

COLLEGE OF ENGINEERING

CAGAYAN STATE UNIVERSITY – CARIG CAMPUS

IN PARTIAL FULFILLMENT OF THE REQUIREMENTS

FOR THE DEGREE OF

BACHELOR OF SCIENCE IN ELECTRONICS ENGINEERING

CHAPTER I: INTRODUCTION

1.1 Background of the Study

Road traffic injuries represent one of the most persistent and preventable public health crises of the modern era. The World Health Organization reports that approximately 1.19 million lives are claimed by road traffic crashes annually, with an additional 20 to 50 million individuals sustaining non-fatal injuries each year [1]. In the Philippines, the burden is particularly severe: road incidents consistently rank among the leading causes of injury-related mortality, with thousands of fatalities and tens of thousands of injuries documented annually by the Philippine Statistics Authority [2]. Critically, this toll extends beyond motorists — pedestrians, cyclists, and motorcyclists constitute a significant proportion of casualties, as does an often-overlooked category of victim: road users who are incapacitated through falls into roadside hazards such as open manholes, drainage canals, and embankments, where they may remain concealed from passing traffic and unable to receive timely assistance.

A critical determinant of survival following traumatic injury is the "Golden Hour" — the immediate post-trauma period during which prompt medical intervention most decisively improves patient outcomes [3]. A primary impediment to effective emergency response in road corridor environments is the failure of incident notification, particularly when the victim is rendered unconscious, located in an isolated road section, or submerged in a concealed roadside hazard. In such scenarios, no self-report is possible, and bystanders may be entirely absent.

Conventional automated accident detection systems have addressed this gap primarily through cellular network-based alert modules [4]. While viable in dense urban environments, such systems impose significant constraints in road corridor deployment: reliance on cellular network availability, high power consumption that reduces wearable device battery life, and per-message operational costs that render large-scale deployment economically prohibitive [5]. Furthermore, these systems provide no local feedback to the wearer regarding device operational status — a critical deficiency for a life-safety device that must be implicitly trusted.

The integration of IoT technologies into road safety monitoring has gained significant momentum in recent years [12]. However, existing road-area systems predominantly address vehicular crashes and are designed for a single class of road user — the motorist — leaving pedestrians, cyclists, road workers, and other non-motorized road users without equivalent protection. Moreover, current implementations rarely account for fall-into-hazard incidents, which are structurally distinct from vehicular impacts and require a detection approach calibrated for human body dynamics rather than vehicle kinematics.

This study proposes a road-corridor-specific, infrastructure-independent accident detection and emergency alert system designed to serve all categories of road users. The system employs a wearable transmitter unit that continuously monitors the wearer's motion and location. Upon confirming an incident through a multi-stage detection algorithm, the unit wirelessly transmits an emergency alert packet containing the victim's identity and GPS coordinates to a fixed receiver station operated by emergency responders, where an automated interface displays the victim's medical profile and live location — enabling immediate, zero-installation incident dispatch.

1.2 Conceptual Framework

The conceptual framework of this study is structured around the Input–Process–Output (IPO) model, detailing the data and control flow from raw sensor acquisition through wireless transmission to final emergency response.

The input stage encompasses all raw data streams and user-defined parameters required for system operation. This includes geospatial data (longitude and latitude) from the GPS module, tri-axial motion data (acceleration and angular velocity) from the inertial measurement unit (IMU), interactive user commands (Arm/Disarm and wireless link test) through the transmitter's web-based GUI, a hard-coded unique device token per transmitter unit, and diagnostic status signals representing GPS satellite lock, wireless link health, and IMU calibration state.

The processing stage transforms raw sensor inputs into verified emergency information through a layered computational pipeline. The transmitter first performs sensor fusion to compute real-time orientation angles alongside the orientation-independent resultant acceleration magnitude. These values undergo a three-stage sequential threshold analysis — the Fall-Impact-Stillness finite state machine — to distinguish genuine road user incidents from routine motion. A parallel environmental analysis module evaluates acceleration standard deviation and orientation variance over a rolling sample buffer to detect secondary hazard signatures such as ground shock and wave instability. Confirmed events trigger wireless packet formation: a fixed-payload RF packet encoding the device token and GPS coordinates is transmitted to the designated receiver station. At the receiver, the module decodes the packet, parses the device token and coordinate fields, and executes keyboard emulation to automate emergency URL navigation.

The output stage provides two parallel deliverables. Locally, the transmitter GUI presents real-time IMU telemetry, GPS lock status, wireless link readiness, and fall detection pipeline stage progress to the device operator. Remotely, the receiver generates a dynamic emergency URL in the format: https://danger-monitor-profile.netlify.app/?token=[TOKEN]&loc=[LAT],[LNG]. This URL resolves to a token-routed emergency web profile displaying the registered victim's identity, medical information, and a live Google Maps location pin, facilitating immediate incident confirmation and emergency dispatch.

1.3 Objectives of the Study

The general objective of this study is to design and implement a real-time road user accident detection and emergency alert system, utilizing a GUI-integrated wearable transmitter and a web-based HID-automated emergency dispatch interface, without dependence on cellular network infrastructure.

Specifically, the study aims to:

1. To implement real-time GPS-based geospatial data acquisition with a last-known-location fallback mechanism for incident location reporting.

2. To develop a three-stage Fall-Impact-Stillness detection algorithm using IMU sensor data to identify genuine road user incidents and minimize false-positive alerts from routine motion.

3. To implement a token-based device identification and web profile routing system supporting a minimum of five uniquely registered road user devices.

4. To develop an ESP32-hosted web-based GUI displaying real-time IMU telemetry, GPS status, fall detection pipeline stage, and system arm state.

5. To implement an HID receiver module that automatically navigates the connected workstation browser to the victim's emergency web profile without requiring additional software installation.

1.5 Statement of the Problem

The general problem addressed by this research is the absence of a low-cost, infrastructure-independent, road-corridor-specific accident detection and emergency alert system capable of serving all categories of road users — including those rendered unconscious by vehicular crash, pedestrian impact, or fall into roadside hazards — without dependence on cellular network availability or specialized software at the receiver station.

Specifically, the study seeks to answer:

1. How can real-time GPS-based location data be acquired and maintained for incident location reporting when satellite signal may be temporarily obstructed?

2. How can a multi-stage motion detection algorithm distinguish genuine road user incidents from routine activities using IMU sensor data?

3. How can a token-based identification system correctly route emergency alerts from each registered transmitter device to the corresponding victim emergency web profile?

4. How can a web-based GUI provide real-time system feedback to the device operator through the transmitter's onboard access point mode?

5. How can the receiver module automate browser-based emergency reporting at the station workstation without requiring any additional software installation?

1.6 Scope and Limitations of the Study

The study is scoped to road corridor environments within effective direct wireless communication range of the receiver station. RF communication range is subject to line-of-sight conditions, environmental obstructions, and antenna type — ranging from approximately 100 meters with standard PCB antennas to 800 meters with external high-gain antennas. GPS coordinate accuracy is subject to satellite availability and signal obstruction; the last-known-location strategy maintains coordinate availability but does not guarantee positional accuracy at the precise moment of impact. The Fall-Impact-Stillness detection algorithm is calibrated for human body dynamics in road incident scenarios and may not generalize to all edge-case physical activities. The system supports a minimum of five registered device profiles in the current implementation, expandable through software configuration without hardware modification. HID keyboard emulation requires an active browser window on the receiver workstation and has been validated for standard desktop operating systems; behavior on mobile or non-standard environments is not within the scope of this study.

1.7 Future Improvements

The following enhancement is identified as a priority for future development of the system:

NRF24L01-Based Road Corridor Repeater Relay Network. A key limitation of the current implementation is the single-hop wireless transmission range, which constrains deployment to within direct communication distance of the receiver station. Future work will address this through the design and deployment of an NRF24L01-based road corridor repeater network, wherein intermediate relay nodes are deployed at fixed intervals along the road segment. These nodes will receive and re-transmit emergency alert packets hop-by-hop from any point-of-incident transmitter to the designated receiver station, extending coverage to longer road corridors independent of cellular infrastructure. This enhancement is expected to substantially increase the system's practical deployment range and scalability.

1.8 Significance of the Study

This study is significant as it provides a low-cost, license-free, and cellular-independent road safety detection and alert system that extends protection to all categories of road users — not exclusively motorists — and demonstrates a viable IoT architecture for infrastructure-independent road corridor emergency communication [12]. The following beneficiaries stand to gain from this work:

EMERGENCY RESPONDERS: Immediate, automated alerts with GPS-pinned victim location and pre-loaded medical information reduce dispatch decision time and eliminate the need for manual incident reporting.

ALL ROAD USERS: Motorcyclists, cyclists, pedestrians, road workers, and any individual in a road corridor environment — including those involved in non-vehicular incidents such as falls into manholes or drainage canals — are afforded equivalent protection.

ROAD AGENCIES AND LOCAL GOVERNMENT UNITS: The modular, open-hardware architecture enables scalable deployment along managed road corridors as a complement to or replacement for cellular-dependent safety infrastructure, with significantly lower operational costs.

VULNERABLE ROAD USER POPULATIONS: Elderly pedestrians, solo travelers, and individuals working in isolated road sections receive automated emergency notification that does not require any conscious action on the part of the victim post-incident.

THE ECE AND IoT COMMUNITY: This study demonstrates the viability of 2.4 GHz ISM-band RF communication for life-safety applications and provides a replicable open-hardware framework for road corridor safety monitoring systems.

1.9 Definition of Terms

The following terms are operationally defined for the purposes of this study:

Acceleration Magnitude (Aₘ). The orientation-independent resultant of the three-axis accelerometer readings, computed as Aₘ = √(aₓ² + aᵧ² + aᵨ²), expressed in gravitational units (g). Used as the primary input metric for all fall detection threshold evaluations.

Arming Mode. The operational state in which the wearable transmitter actively monitors sensor data for fall and environmental hazard triggers and is authorized to generate and transmit alert packets.

Fall-Impact-Stillness State Machine. A three-stage sequential finite state machine implemented on the transmitter microcontroller that confirms a road user incident only when freefall, impact, and post-impact stillness conditions are observed in strict sequential order, eliminating false positives from single-condition motion events.

Freefall State. A period during which Aₘ falls below 0.4g and is sustained for at least 100 milliseconds, indicating near-weightlessness consistent with an uncontrolled fall or loss of ground contact.

Golden Hour. The critical period immediately following traumatic physical injury during which prompt medical intervention most significantly improves patient survival outcomes [3].

Ground Shock. An environmental hazard signature detected when the standard deviation of Aₘ over the rolling sample buffer meets or exceeds 0.40g while orientation standard deviations remain below 10°, indicating a sudden vertical structural impact without significant tilt.

HID Emulation. The use of the receiver microcontroller as a USB Human Interface Device to simulate keyboard input on the connected workstation, enabling automated browser navigation to the victim's emergency web profile without host software installation [13].

Impact State. A transient spike in Aₘ exceeding 3.0g occurring within 500 milliseconds of confirmed freefall termination, indicating collision with a surface or object.

NRF24L01+. A single-chip 2.4 GHz ISM-band transceiver used in this system as the wireless communication module for both the wearable transmitter unit and the fixed receiver station [6].

Pitch. The rotation of the device around its lateral axis, computed via the complementary filter as: Pitch = tan⁻¹(aₓ / √(aᵧ² + aᵨ²)).

Roll. The rotation of the device around its longitudinal axis, computed via the complementary filter as: Roll = tan⁻¹(aᵧ / √(aₓ² + aᵨ²)).

Stillness State. A post-impact period during which the standard deviation of Aₘ remains below 0.15g over a two-second observation window, indicating the absence of conscious voluntary movement and consistent with incapacitation.

Token-Based Identification. A unique alphanumeric device identifier (e.g., "DM-001") hard-coded into each transmitter unit and embedded in every wireless alert packet, used to route alerts to the corresponding registered emergency profile on the hosted web platform.

Wave Motion. An environmental hazard signature detected when the standard deviation of Aₘ meets or exceeds 0.24g while orientation standard deviations in roll or pitch meet or exceed 10°, indicating persistent instability such as tumbling, rocking, or uncontrolled movement.

References

[1] World Health Organization, "Global Status Report on Road Safety 2023," World Health Organization, Geneva, Switzerland, 2023.

[2] Philippine Statistics Authority, "Deaths by External Causes," Philippine Statistics Authority, Quezon City, Philippines, 2022.

[3] D. D. Trunkey, "Trauma," Scientific American, vol. 249, no. 2, pp. 28–35, Aug. 1983.

[4] A. Srivastava, A. Bhardwaj, and S. Saraswat, "AGPS and GSM based vehicle tracking and employee security system," in Proc. 2016 IEEE Int. Conf. on Recent Trends in Electronics, Information & Communication Technology (RTEICT), Bangalore, India, 2016, pp. 1–5.

[5] M. A. Al-Khedher, "Hybrid GPS-GSM localization of automobile tracking system," International Journal of Computer Science & Information Technology, vol. 3, no. 6, pp. 75–85, Dec. 2011.

[6] Nordic Semiconductor ASA, "nRF24L01+ Single Chip 2.4GHz Transceiver Product Specification v1.0," Nordic Semiconductor ASA, Trondheim, Norway, 2008.

[7] InvenSense Inc., "MPU-6000 and MPU-6050 Product Specification Revision 3.4," InvenSense Inc., San Jose, CA, USA, 2013.

[8] T. Shany, S. J. Redmond, M. R. Narayanan, and N. H. Lovell, "Sensors-based wearable systems for monitoring of human movement and falls," IEEE Sensors Journal, vol. 12, no. 3, pp. 658–670, Mar. 2012.

[9] A. K. Bourke and G. M. Lyons, "A threshold-based fall-detection algorithm using a bi-axial gyroscope sensor," Medical Engineering & Physics, vol. 30, no. 1, pp. 84–90, Jan. 2008.

[10] S. Abbate, M. Avvenuti, F. Bonatesta, G. Cola, P. Corsini, and A. Vecchio, "A smartphone-based fall detection system," Pervasive and Mobile Computing, vol. 8, no. 6, pp. 883–899, Dec. 2012.

[11] R. Igual, C. Medrano, and I. Plaza, "Challenges, issues and trends in fall detection systems," BioMedical Engineering OnLine, vol. 12, no. 1, p. 66, Jul. 2013.

[12] A. Zanella, N. Bui, A. Castellani, L. Vangelista, and M. Zorzi, "Internet of things for smart cities," IEEE Internet of Things Journal, vol. 1, no. 1, pp. 22–32, Feb. 2014.

[13] USB Implementers Forum, "Device Class Definition for Human Interface Devices (HID) Version 1.11," USB Implementers Forum, Portland, OR, USA, 2001.

[14] Espressif Systems, "ESP32 Technical Reference Manual v5.1," Espressif Systems, Shanghai, China, 2023.

[15] U-blox AG, "NEO-7 u-blox 7 GNSS Modules Data Sheet," u-blox AG, Thalwil, Switzerland, 2014.

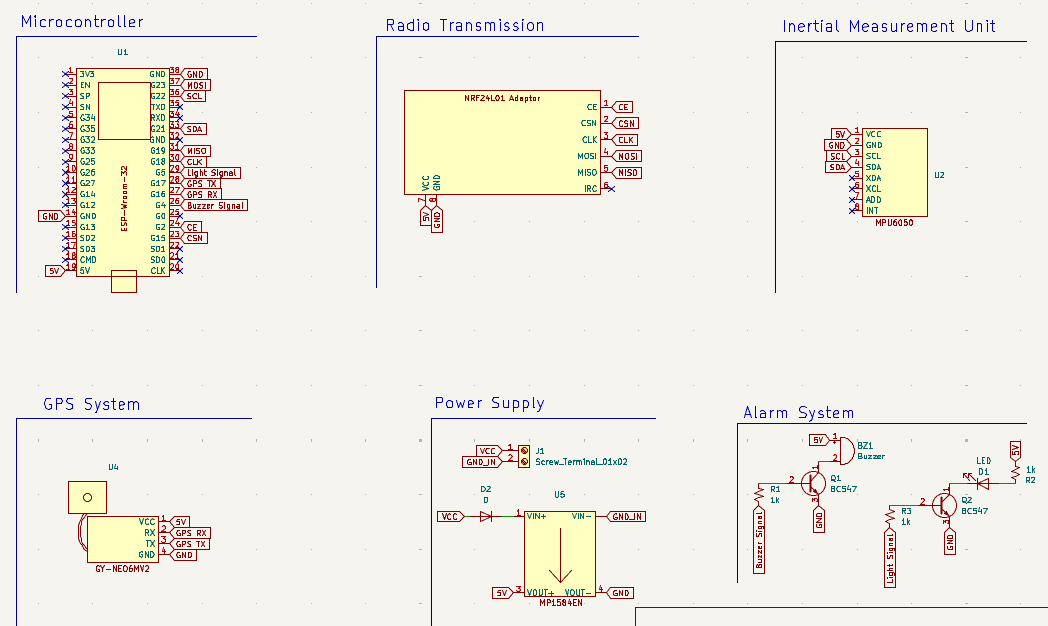
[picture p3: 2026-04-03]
Transmitter/pcb/Schematic Screenshot.png

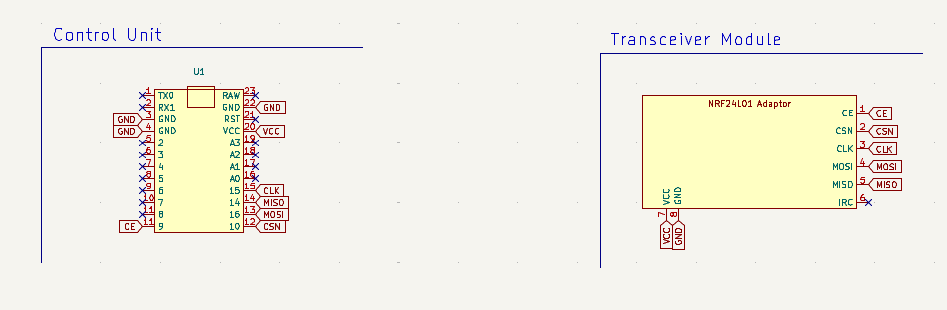
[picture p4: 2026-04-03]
Receiver/pcb/Danger Monitor System_Receiver Schematic.png

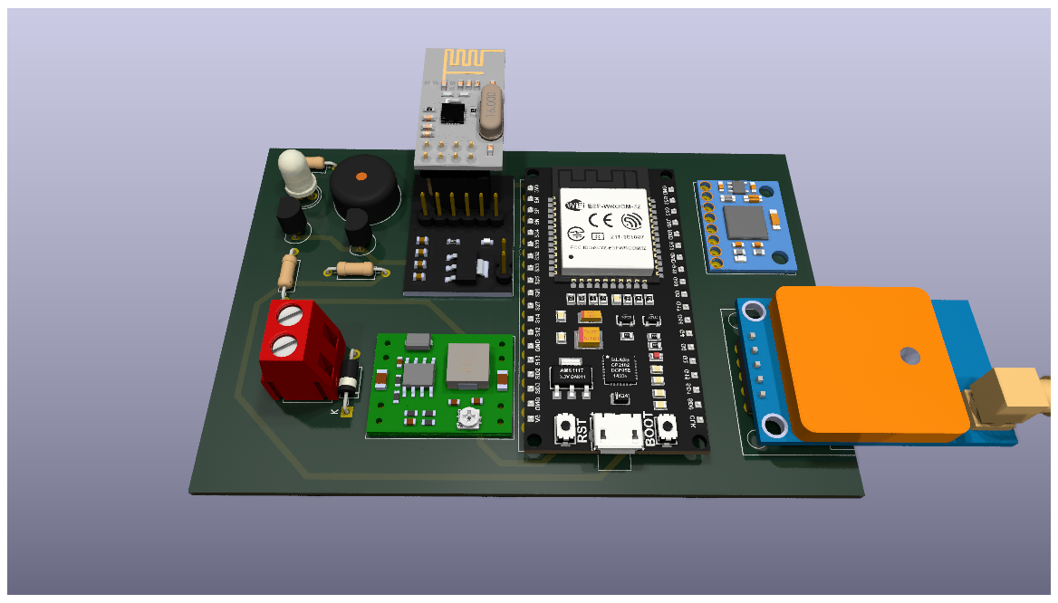
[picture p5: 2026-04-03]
images/Danger Monitor System 3D 2.png

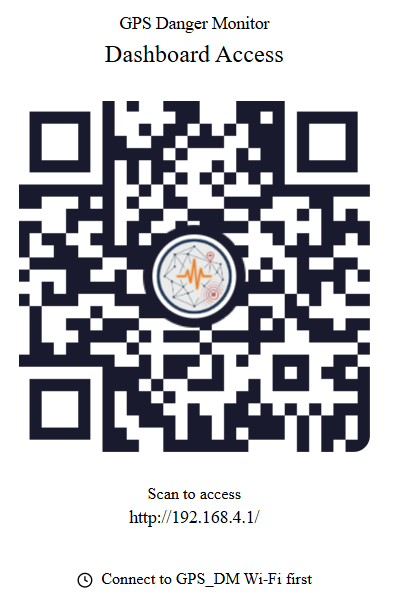
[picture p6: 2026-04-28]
images/QR_webserver.png

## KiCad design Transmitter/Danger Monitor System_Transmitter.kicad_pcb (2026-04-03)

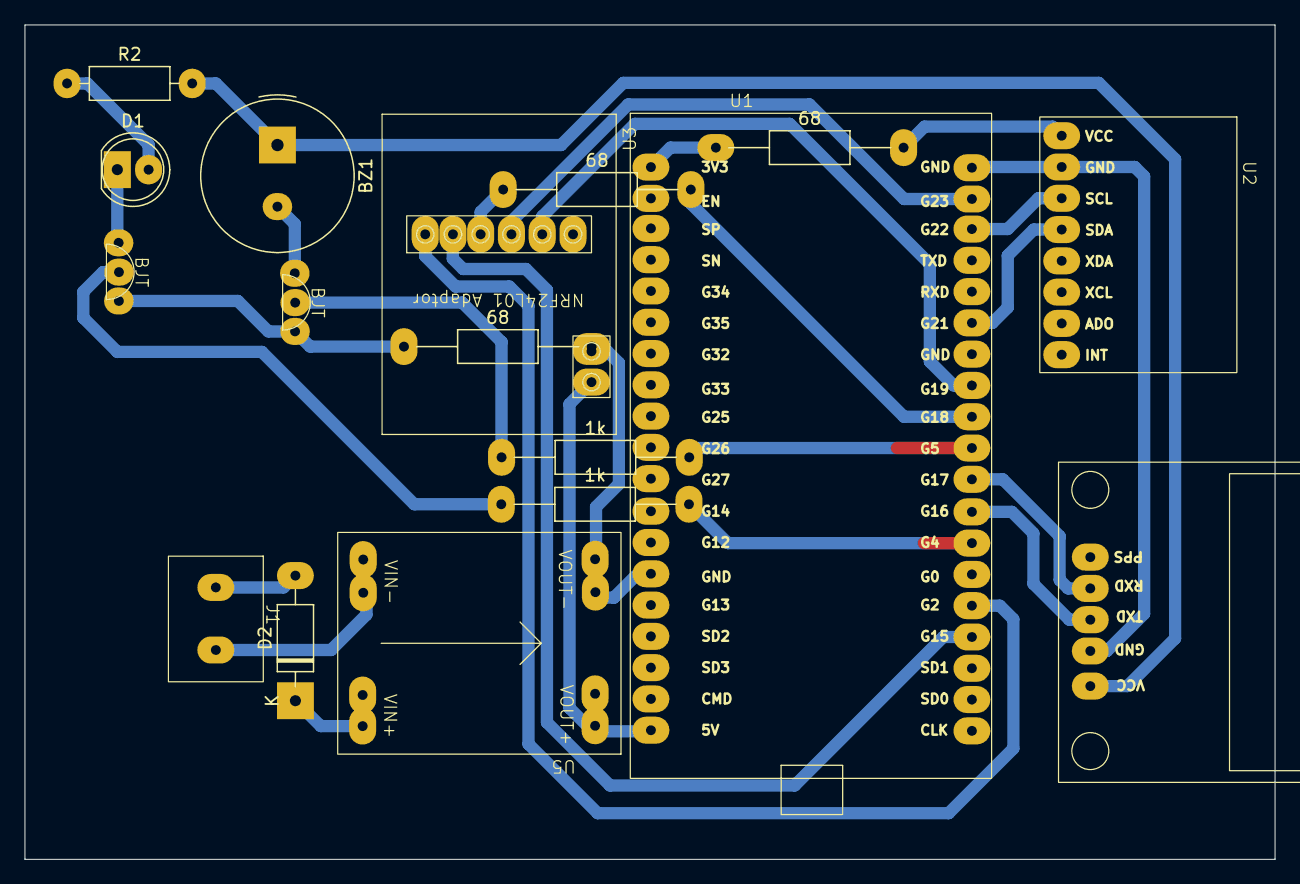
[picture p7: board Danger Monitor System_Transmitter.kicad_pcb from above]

Board: 2 copper layers, 101.5 x 67.8 mm, 17 parts (0 on the bottom side), 22 nets.

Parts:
1k, 1k#2, 68, 68#2, 68#3: R_Axial_DIN0207_L6.3mm_D2.5mm_P15.24mm_Horizontal
BJT: 2N2222A
BJT#2: 2N2222A
BZ1: Buzzer; Buzzer_TDK_PS1240P02BT_D12.2mm_H6.5mm
D1: LED; LED_D5.0mm_Clear
D2: D; D_A-405_P10.16mm_Horizontal
J1: Screw_Terminal_01x02; Screw Terminal 2 Pin
R2: 1k; R_Axial_DIN0207_L6.3mm_D2.5mm_P10.16mm_Horizontal
U1: ESP-WROOM-32
U2: MPU-6050
U3: NRF24L01 Adaptor
U4: NEO7
U5: MP1584EN

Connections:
3V3: 68#3.1, 68#3.2, U1.1 (3V3), U2.1 (VCC)
5V: BZ1.1 (+), R2.2, U1.19 (5V), U3.7 (VCC), U4.1 (VCC), U5.1 (VIN+)
Buzzer Signal: 1k.2, U1.29 (G5)
CE: U1.24 (G2), U3.1 (CE)
CLK: 68.1, 68.2, U1.30 (G18), U3.3 (CLK)
CSN: U1.23 (G15), U3.2 (CSN)
GND: 68#2.1, 68#2.2, BJT.2, BJT#2.2, U1.14 (GND), U1.38 (GND), U2.2 (GND), U3.8 (GND), U4.2 (RX), U5.7
GND_IN: J1.2, U5.8
GPS RX: U1.28 (G17), U4.4 (GND)
GPS TX: U1.27 (G16), U4.3 (TX)
Light Signal: 1k#2.2, U1.26 (G4)
MISO: U1.31 (G19), U3.5 (MISO)
MOSI: U1.37 (G23), U3.4 (MOSI)
unnamed: BJT.3, BZ1.2 (-)
unnamed: D1.2 (A), R2.1
unnamed: BJT#2.3, D1.1 (K)
unnamed: D2.1 (K), U5.3 (VOUT+)
unnamed: 1k.1, BJT.1
unnamed: 1k#2.1, BJT#2.1
SCL: U1.36 (G22), U2.3 (SCL)
SDA: U1.33 (G21), U2.4 (SDA)
VCC: D2.2 (A), J1.1

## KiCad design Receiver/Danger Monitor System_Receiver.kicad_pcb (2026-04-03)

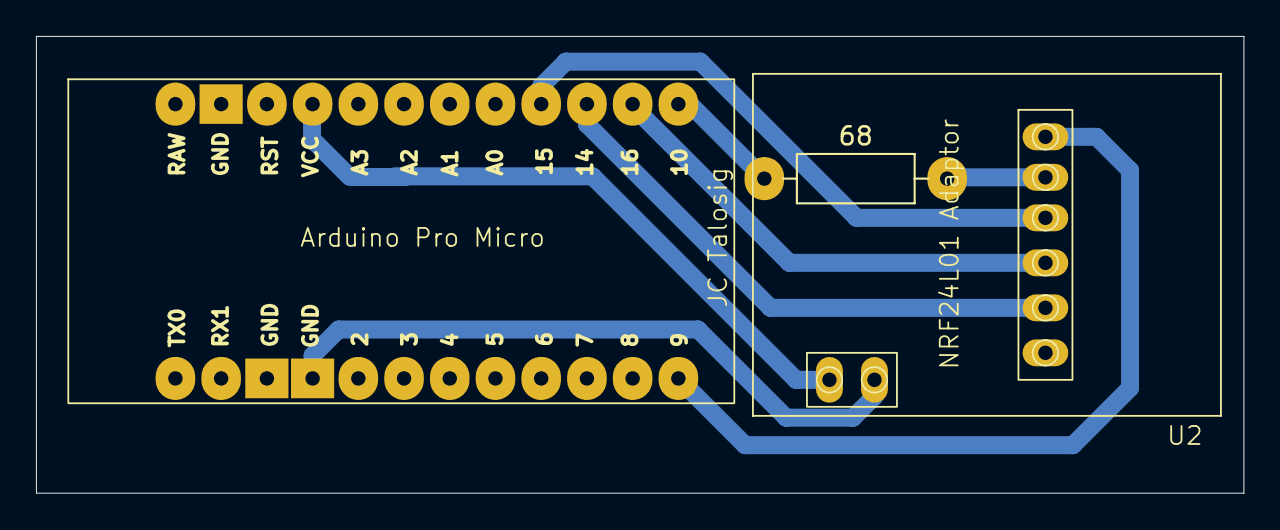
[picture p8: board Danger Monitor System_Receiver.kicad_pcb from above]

Board: 2 copper layers, 67.1 x 25.4 mm, 3 parts (0 on the bottom side), 7 nets.

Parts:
68: R_Axial_DIN0207_L6.3mm_D2.5mm_P10.16mm_Horizontal
U1: Pro Micro
U2: NRF24L01 Adaptor

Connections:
CE: U1.12 (10), U2.1 (CE)
CLK: U1.16 (A0), U2.3 (CLK)
CSN: 68.1, 68.2, U1.13 (16), U2.2 (CSN)
GND: U1.3 (GND), U1.4 (GND), U1.22 (GND), U2.8 (GND)
MISO: U1.15, U2.5 (MISO)
MOSI: U1.14, U2.4 (MOSI)
VCC: U1.21 (RST), U2.7 (VCC)

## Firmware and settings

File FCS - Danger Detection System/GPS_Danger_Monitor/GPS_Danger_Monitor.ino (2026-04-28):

/*  GPS_Danger_Monitor.ino  –  v3.0  (Diagnostics + Simulation Edition)
 *  ESP32 + TinyGPS++ + MPU-6050 + NRF24L01 + WebServer (AP mode)
 *
 *  ── Detection pipeline (thesis-grade) ──────────────────────────────────
 *  PRIMARY: Fall-Impact-Stillness FSM
 *    1. FREEFALL  – A_m < 0.40 g  for ≥ 100 ms
 *    2. IMPACT    – A_m > 3.00 g  within 500 ms of freefall end
 *    3. STILLNESS – σ(A_m)< 0.15 g over 2 s after impact
 *
 *  SECONDARY: Parallel event detectors
 *    SKID/SLIDE   – lateral ay > 0.70 g  AND  roll-rate gx > 50 °/s
 *                   sustained ≥ 200 ms  (Ref: motorcycle crash paper, 96% acc)
 *    DIRECT IMPACT– A_m spike > 4.00 g  without freefall precondition
 *                   (Ref: construction-site LF falls 4-9g range, Sensors 2022)
 *
 *  ── New in v3.0 ─────────────────────────────────────────────────────────
 *  • 20-shot NRF burst test (non-blocking, 100 ms spacing)
 *  • GPS fix-time tracking (fix count, avg time-to-fix)
 *  • Fall detection stats (response time, false-positive rate, skid/impact counts)
 *  • IMU simulation mode (Skid / Fall / Direct-Impact waveforms)
 *  • New endpoints: /run-burst  /burst-results.json  /diag-stats.json  /simulate
 *
 *  ── Pins ────────────────────────────────────────────────────────────────
 *    GPS  UART1  : RX=16, TX=17 @ 9600
 *    MPU6050 I2C : SDA=21, SCL=22, addr=0x68
 *    NRF24       : MOSI=23, MISO=19, SCK=18, CE=2, CSN=15
 *    LED         : GPIO 4   |   Buzzer : GPIO 5
 *
 *  Libraries: TinyGPSPlus (Mikal Hart), RF24 (TMRh20)
 */

#include <WiFi.h>
#include <WebServer.h>
#include <TinyGPS++.h>
#include <HardwareSerial.h>
#include <Wire.h>
#include <SPI.h>
#include <RF24.h>
#include <math.h>
#include "web_ui.h"

/* ═══════════════════════ USER CONFIG ═══════════════════════════════════ */
static const int      GPS_RX   = 16;
static const int      GPS_TX   = 17;
static const uint32_t GPS_BAUD = 9600;

const char*  DEVICE_TOKEN = "DM-001";

const char*  AP_SSID    = "GPS Danger Monitor";
const char*  AP_PASS    = "";
IPAddress    apIP       (192,168,4,1);
IPAddress    apGateway  (192,168,4,1);
IPAddress    apSubnet   (255,255,255,0);

/* ── Fall-Impact-Stillness thresholds ── */
const float    FREEFALL_G        = 0.40f;   // g  – below = freefall
const uint32_t FREEFALL_DUR_MS   = 100;     // ms – must persist
const float    IMPACT_G          = 3.00f;   // g  – spike above = impact
const uint32_t IMPACT_WINDOW_MS  = 500;     // ms – window after freefall
const uint32_t STILLNESS_DUR_MS  = 2000;    // ms – observe for stillness
const float    STILLNESS_STD_MAX = 0.15f;   // g  – σ below = person still

/* ── Skid detection thresholds (Ref: Motorcycle IoT crash paper 2023) ── */
const float    SKID_LATERAL_G    = 2.0f;   // g   – lateral ay threshold
const float    SKID_ROLL_RATE    = 330.0f;   // °/s – roll-rate gx threshold
const uint32_t SKID_DUR_MS       = 200;     // ms  – both must persist

/* ── Direct-impact threshold (Ref: Sensors 2022, construction-site falls) */
const float    IMPACT_DIRECT_G   = 4.50f;   // g  – single spike, no freefall
const uint32_t IMPACT_DEBOUNCE   = 5000;    // ms – re-alert dead-time

/* ── Environmental instability (secondary alert) ── */
const float    ACC_STD_DANGER    = 0.40f;
const float    ROLL_PITCH_STD    = 10.0f;
const uint32_t ANALYZE_EVERY_MS  = 1000;
const uint32_t CALIB_MS          = 3000;
/* ══════════════════════════════════════════════════════════════════════ */

/* ── Hardware ── */
TinyGPSPlus    gps;
HardwareSerial gpsSerial(1);
WebServer      server(80);

#define NRF_CE  2
#define NRF_CSN 15
RF24 radio(NRF_CE, NRF_CSN);
const uint64_t NRF_ADDRESS = 0xE8E8F0F01LL;
const uint8_t  NRF_PAYLOAD = 32;

#define ALERT_LED_PIN 4
#define BUZZER_PIN    5

/* ── MPU-6050 ── */
const uint8_t MPU_ADDR = 0x68;
float ax, ay, az, gx, gy, gz;
float aBiasX=0, aBiasY=0, aBiasZ=0;
float gBiasX=0, gBiasY=0, gBiasZ=0;
float roll=0, pitch=0;
const float ALPHA = 0.02f;

/* ── GPS state ── */
float    lastLat=0, lastLng=0;
bool     hasFix=false;

/* ── GPS diagnostics ── */
uint32_t gpsFixCount      = 0;
uint32_t gpsTotalFixMs    = 0;
uint32_t gpsSearchStart   = 0;    // millis when searching started (boot or last lost)

/* ── System state ── */
bool    armed      = true;
String  lastEvent  = "System boot";
uint32_t lastAnalyze = 0;
bool    nrfReady   = false;
bool    streamToSerial = true;

/* ── Rolling statistics buffers ── */
const int BUF_N = 50;
float magBuf[BUF_N], rollBuf[BUF_N], pitchBuf[BUF_N];
int   bufIdx=0, bufCount=0;

/* ── Stillness buffer (post-impact) ── */
const int STILL_BUF_N = 40;
float stillBuf[STILL_BUF_N];
int   stillIdx=0, stillCount=0;

/* ══════════════ Fall State Machine ══════════════════════════════════ */
enum FallState { FS_IDLE, FS_FREEFALL, FS_WAIT_IMPACT, FS_STILLNESS, FS_CONFIRMED };
FallState fallState = FS_IDLE;
uint32_t  fsTimer   = 0;

/* ── Fall diagnostics ── */
uint32_t fallStartMs      = 0;   // when FS_FREEFALL→FS_WAIT_IMPACT transition happened
uint32_t fallEventCount   = 0;   // confirmed freefalls (past 100ms threshold)
uint32_t fallConfirmCount = 0;   // full Freefall+Impact+Stillness confirmations
uint32_t fallCancelCount  = 0;   // events that were canceled (false positives)
uint32_t fallTotalRespMs  = 0;   // sum of response times for avg computation

/* ── Secondary event counters ── */
uint32_t skidCount   = 0;
uint32_t impactCount = 0;

/* ── Skid state ── */
bool     inSkid    = false;
uint32_t skidTimer = 0;

/* ── Direct impact debounce ── */
uint32_t lastImpactAlert = 0;

/* ══════════════ SOS Alert (non-blocking) ════════════════════════════ */
bool alertActive = false;
struct AlertStep { bool on; uint16_t ms; };
const AlertStep SOS_STEPS[] = {
  {true,150},{false,150},{true,150},{false,150},{true,150},{false,150},
  {true,450},{false,150},{true,450},{false,150},{true,450},{false,150},
  {true,150},{false,150},{true,150},{false,150},{true,150},{false,600}
};
const int SOS_N = sizeof(SOS_STEPS)/sizeof(SOS_STEPS[0]);
int      sosIdx        = 0;
uint32_t sosNextChange = 0;

/* ══════════════ NRF Burst Test ══════════════════════════════════════ */
#define BURST_N 20
struct BurstResult { bool ok; uint16_t delayMs; };
BurstResult burstResults[BURST_N];
bool     burstPending = false;
int      burstDone    = -1;      // -1 = never run, ≥0 = packets completed
int      burstCurrent = 0;
uint32_t burstNextT   = 0;

/* ══════════════ IMU Simulation Mode ════════════════════════════════ */
enum SimEvent { SIM_NONE, SIM_SKID, SIM_FALL, SIM_IMPACT };
SimEvent simEvent  = SIM_NONE;
uint32_t simStart  = 0;
bool     simMode   = false;  // when true: suppress real NRF alerts, use test packets

/* ════════════════════════════════════════════════════════════════════
 *  IMU SIMULATION WAVEFORM DEFINITIONS
 *  All values are override targets for global ax/ay/az/gx/gy/gz.
 *  The complementary filter runs normally on these overridden values
 *  so the FSM processes them identically to real sensor data.
 *
 *  Threshold annotations (shown on dashboard waveform):
 *    Freefall line   : aMag = 0.40 g  (orange dashed)
 *    Skid lateral    : ay   = 0.70 g  (yellow dashed)
 *    Impact line     : aMag = 3.00 g  (red dashed)
 *    Direct impact   : aMag = 4.00 g  (red solid)
 * ══════════════════════════════════════════════════════════════════ */
void applySimulation() {
  if (simEvent == SIM_NONE) return;
  uint32_t t = millis() - simStart;

  switch (simEvent) {
    /* ── SKID WAVEFORM ────────────────────────────────────────────
     *  Based on: motorcycle crash paper threshold 0.70g, 96% accuracy
     *  + airbag paper: angular velocity ≥ 30°/s for falling motion
     *
     *  Simulates: person skidding sideways on wet surface.
     *  ay (lateral) rises to 0.85g, gx (roll rate) to 55°/s.
     *  aMag ≈ 1.32g – elevated but below impact threshold (safe).
     */
    case SIM_SKID: {
      float ph = (float)t / 300.0f * 3.14159f;
      float env = (ph < 3.14159f) ? sinf(ph) : 0.0f;
      if (env < 0) env = 0;
      ay = 0.85f * env;            // lateral spike (triggers SKID_LATERAL_G > 0.70g)
      gx = 55.0f * env;            // roll rate    (triggers SKID_ROLL_RATE > 50°/s)
      az = 0.95f;                  // mostly upright
      ax = 0.05f;
      gy = gz = 0.0f;
      if (t >= 700) {
        ax=ay=gz=gx=gy=0; az=1.0f;
        simEvent = SIM_NONE; simMode = false;
        lastEvent = "SIM done: Skid drill complete";
      } else if (env > 0.82f) {
        lastEvent = "SIM: SKID – lateral " + String(ay,2) + "g + roll " + String(gx,0) + "°/s";
      }
      break;
    }

    /* ── FALL WAVEFORM ────────────────────────────────────────────
     *  Based on: SisFall dataset, airbag paper (AR ≤ 0.38g),
     *  construction-site impact 4-9g (Sensors 2022)
     *
     *  Phase 0   (0–100ms): pre-fall lean, aMag drops to ~0.55g
     *  Phase 1 (100–280ms): freefall, aMag ≈ 0.18g, pitch/roll diverge
     *  Phase 2 (280–330ms): IMPACT spike, aMag = 4.8g  
     *  Phase 3 (330–2600ms): stillness, aMag ≈ 0.97g, σ < 0.05g
     *  → FSM detects and fires alert at ~2.6 s
     */
    case SIM_FALL: {
      if (t < 100) {
        // Pre-fall: body leans, some acceleration change
        float r = (float)t / 100.0f;
        ax = 0.0f + 0.35f * r;   ay = 0.0f; az = 1.0f - 0.45f * r;
        gx = 15.0f * r; gy = gz = 0.0f;
        lastEvent = "SIM FALL: pre-fall lean";
      } else if (t < 280) {
        // Freefall: all axes near zero – "weightlessness"
        ax = 0.05f;  ay = 0.04f;  az = 0.12f;   // aMag ≈ 0.18g < 0.40g ✓
        gx = 30.0f;  gy = 5.0f;   gz = 3.0f;
        lastEvent = "SIM FALL: FREEFALL (~0.18g)";
      } else if (t < 330) {
        // IMPACT spike
        ax = -3.0f;  ay = 1.8f;   az = 3.2f;    // aMag ≈ 4.8g > 3.0g ✓
        gx = 120.0f; gy = 80.0f;  gz = 60.0f;
        lastEvent = "SIM FALL: IMPACT SPIKE (~4.8g)";
      } else if (t < 2650) {
        // Stillness – person motionless after impact
        ax = 0.0f;   ay = 0.02f;  az = 0.97f;   // aMag ≈ 0.97g, very quiet
        gx = 0.5f;   gy = 0.3f;   gz = 0.2f;
        if (t > 400) lastEvent = "SIM FALL: stillness (σ < 0.05g)";
      } else {
        // Reset
        ax=0; ay=0; az=1.0f; gx=gy=gz=0;
        simEvent = SIM_NONE; simMode = false;
        lastEvent = "SIM done: Fall drill complete";
      }
      break;
    }

    /* ── DIRECT IMPACT WAVEFORM ────────────────────────────────────
     *  Based on: construction-site falls 4-9g range (Sensors 2022)
     *  Simulates: side collision / hard stop while stationary.
     *  Gaussian pulse: peak 5.2g at t≈40ms, σ=18ms.
     *  No freefall precondition → fires IMPACT_DIRECT_G (4.0g) detector.
     */
    case SIM_IMPACT: {
      float sigma = 18.0f;
      float gauss = expf(-0.5f * powf(((float)t - 40.0f) / sigma, 2.0f));
      ax = -3.2f * gauss;
      ay =  2.0f * gauss;
      az =  1.0f + 2.8f * gauss;   // aMag ≈ 5.2g peak
      gx =  30.0f * gauss;
      gy = gy = gz = 0.0f;
      if (t < 200) {
        if (gauss > 0.5f) lastEvent = "SIM IMPACT: spike " + String(sqrt(ax*ax+ay*ay+az*az),1) + "g";
      } else {
        ax=0; ay=0; az=1.0f; gx=gy=gz=0;
        simEvent = SIM_NONE; simMode = false;
        lastEvent = "SIM done: Impact drill complete";
      }
      break;
    }

    default: break;
  }
}

/* ═══════════════════════ Utilities ═════════════════════════════════ */
void buzzerOn (uint32_t hz){ tone(BUZZER_PIN, hz); }
void buzzerOff(){ noTone(BUZZER_PIN); }

void mpuWrite(uint8_t reg, uint8_t val){
  Wire.beginTransmission(MPU_ADDR);
  Wire.write(reg); Wire.write(val);
  Wire.endTransmission();
}

void readMPU(){
  Wire.beginTransmission(MPU_ADDR);
  Wire.write(0x3B);
  Wire.endTransmission(false);
  Wire.requestFrom((int)MPU_ADDR, 14, true);

  int16_t rAx=(Wire.read()<<8)|Wire.read();
  int16_t rAy=(Wire.read()<<8)|Wire.read();
  int16_t rAz=(Wire.read()<<8)|Wire.read();
  Wire.read(); Wire.read();
  int16_t rGx=(Wire.read()<<8)|Wire.read();
  int16_t rGy=(Wire.read()<<8)|Wire.read();
  int16_t rGz=(Wire.read()<<8)|Wire.read();

  ax = (rAx/16384.0f) - aBiasX;
  ay = (rAy/16384.0f) - aBiasY;  //calibration formula, since no standard tool, divided by hula hula number
  az = (rAz/16384.0f) - aBiasZ;
  gx = (rGx/131.0f)   - gBiasX;
  gy = (rGy/131.0f)   - gBiasY;
  gz = (rGz/131.0f)   - gBiasZ;
}

void calibrateMPU(){
  aBiasX=aBiasY=aBiasZ=gBiasX=gBiasY=gBiasZ=0;
  const int N=200;
  float sax=0,say=0,saz=0,sgx=0,sgy=0,sgz=0;
  for(int i=0;i<N;i++){
    readMPU();
    sax+=ax; say+=ay; saz+=az;
    sgx+=gx; sgy+=gy; sgz+=gz; //calibratiion process
    delay(CALIB_MS/N);
  }
  aBiasX=sax/N; aBiasY=say/N; aBiasZ=saz/N-1.0f;
  gBiasX=sgx/N; gBiasY=sgy/N; gBiasZ=sgz/N;
}

void updateOrientation(float dt){
  float aRoll  = atan2(ay,az)*57.29578f;
  float aPitch = atan2(-ax,sqrt(ay*ay+az*az))*57.29578f; // roll and pitch calibration
  roll  += gx*dt;  pitch += gy*dt;
  roll  = (1.0f-ALPHA)*roll  + ALPHA*aRoll;
  pitch = (1.0f-ALPHA)*pitch + ALPHA*aPitch;
}

float stddev(float* a, int n){
  if(n<=1) return 0.0f;
  double s=0, s2=0;
  for(int i=0;i<n;i++){ s+=a[i]; s2+=a[i]*a[i]; }
  double v = (s2/n) - (s/n)*(s/n);
  return (v>0) ? (float)sqrt(v) : 0.0f;
}

void pushEnvSample(float mag, float r, float p){
  magBuf[bufIdx]=mag; rollBuf[bufIdx]=r; pitchBuf[bufIdx]=p;
  bufIdx=(bufIdx+1)%BUF_N;
  if(bufCount<BUF_N) bufCount++;
}

/* ══════════════════════ NRF Send ════════════════════════════════════ */
bool nrfSendCoords(float lat, float lng, const String& reason){
  if(!nrfReady) return false;
  char buf[NRF_PAYLOAD] = {0};
  String coord = String(DEVICE_TOKEN) + "," + String(lat,6) + "," + String(lng,6);
  coord.toCharArray(buf, NRF_PAYLOAD);
  bool ok = radio.write(buf, NRF_PAYLOAD);
  lastEvent = ok ? ("NRF sent: " + reason) : "NRF send failed";
  Serial.println(ok ? ("[NRF] Sent: " + coord) : "[NRF] Send FAILED");
  return ok;
}
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
void loop(){
  static uint32_t lastTick = millis();
  uint32_t now = millis();
  float dt = (now - lastTick) / 1000.0f;
  if(dt <= 0) dt = 0.001f;
  lastTick = now;

  server.handleClient();

  /* ── Non-blocking NRF burst test ──────────────────────────────── */
  if(burstPending && burstCurrent < BURST_N && now >= burstNextT){
    char buf[NRF_PAYLOAD] = {0};
    snprintf(buf, NRF_PAYLOAD, "TEST,%02d,%lu", burstCurrent+1, now);
    uint32_t t0 = micros();
    bool ok = radio.write(buf, NRF_PAYLOAD);
    uint32_t dt_us = micros() - t0;
    burstResults[burstCurrent].ok      = ok;
    burstResults[burstCurrent].delayMs = (uint16_t)(dt_us / 1000);
    burstCurrent++;
    burstNextT = now + 100;  // 100 ms between packets
    burstDone  = burstCurrent;
    if(burstCurrent >= BURST_N){
      burstPending = false;
      lastEvent = "Burst test complete (" + String(BURST_N) + " packets)";
      Serial.println("[BURST] Done.");
    }
  }

  /* ── GPS feed ──────────────────────────────────────────────────── */
  while(gpsSerial.available()){
    char c = gpsSerial.read();
    if(gps.encode(c)){
      if(gps.location.isValid() && !hasFix){
        // Acquired fix
        uint32_t fixTime = now - gpsSearchStart;
        gpsTotalFixMs += fixTime;
        gpsFixCount++;
        hasFix  = true;
        lastLat = gps.location.lat();
        lastLng = gps.location.lng();
        Serial.printf("[GPS] Fix acquired in %lu ms. Count: %d\n", fixTime, gpsFixCount);
      } else if(gps.location.isValid() && hasFix){
        lastLat = gps.location.lat();
        lastLng = gps.location.lng();
      }
    }
  }
  // Detect stale fix (age > 8 s → mark as lost)
  if(hasFix && gps.location.age() > 8000){
    hasFix = false;
    gpsSearchStart = now;
    Serial.println("[GPS] Fix lost – searching…");
  }

  /* ── IMU read + simulation override ──────────────────────────── */
  readMPU();
  if(simEvent != SIM_NONE) applySimulation();  // override ax/ay/az/gx/gy/gz
  updateOrientation(dt);

  float aMag = sqrt(ax*ax + ay*ay + az*az);
  pushEnvSample(aMag, roll, pitch);

  /* ══════════════ Fall-Impact-Stillness FSM ══════════════════════ */
  if(armed){
    switch(fallState){

      case FS_IDLE:
        if(aMag < FREEFALL_G){
          fallState = FS_FREEFALL;
          fsTimer   = now;
        }
        break;

      case FS_FREEFALL:
        if(aMag >= FREEFALL_G){
          fallState = FS_IDLE;   // brief dip – not real freefall
        } else if(now - fsTimer >= FREEFALL_DUR_MS){
          fallState    = FS_WAIT_IMPACT;
          fsTimer      = now;
          fallStartMs  = now;    // start responsiveness timer
          fallEventCount++;
          lastEvent    = "Freefall confirmed – awaiting impact…";
          Serial.println("[FALL] Freefall confirmed.");
        }
        break;

      case FS_WAIT_IMPACT:
        if(aMag > IMPACT_G){
          fallState  = FS_STILLNESS;
          fsTimer    = now;
          stillIdx   = stillCount = 0;
          lastEvent  = "Impact detected – checking stillness…";
          Serial.println("[FALL] Impact spike!");
        } else if(now - fsTimer > IMPACT_WINDOW_MS){
          fallState = FS_IDLE;
          fallCancelCount++;
          lastEvent = "No impact in window – cancelled"; //Sudden Accel but no Impact. For Data Recording
          Serial.println("[FALL] No impact – cancel.");
        }
        break;

      case FS_STILLNESS:
        stillBuf[stillIdx % STILL_BUF_N] = aMag;
        stillIdx++;
        stillCount = min(stillIdx, STILL_BUF_N);

        if(now - fsTimer >= STILLNESS_DUR_MS){
          float sig = stddev(stillBuf, stillCount);
          if(sig < STILLNESS_STD_MAX){
            fallState = FS_CONFIRMED;
          } else {
            fallState = FS_IDLE;
            fallCancelCount++;
            lastEvent = "Post-impact movement – user OK (σ=" + String(sig,3) + ")";
            Serial.println("[FALL] User conscious – cancel.");
          }
        }
        break;

      case FS_CONFIRMED:
        fallConfirmCount++;
        fallTotalRespMs += (now - fallStartMs);
        lastEvent = "FALL CONFIRMED – alert sent!";
        Serial.printf("[ALERT] Fall confirmed. Response: %lu ms\n", now - fallStartMs);

        if(!simMode){
          nrfSendCoords(lastLat, lastLng, "Fall confirmed");
        } else {
          nrfSendTest(99, "SIMFALL");
          lastEvent = "SIM FALL confirmed (drill – no real alert)";
        }
        startSOSAlert();
        fallState = FS_IDLE;
        break;
    }
  } else {
    fallState = FS_IDLE;
  }

  /* ══════════ Skid / Slide Detector (parallel, armed + FSM idle) ═══
   *  Ref: Motorcycle crash paper (0.70g lateral, 96% accuracy)
   *       Airbag paper (angular velocity ≥ 30°/s)
   */
  if(armed && fallState == FS_IDLE){
    bool skidCond = (fabsf(ay) > SKID_LATERAL_G) && (fabsf(gx) > SKID_ROLL_RATE);

    if(skidCond){
      if(!inSkid){ inSkid = true; skidTimer = now; }
      else if(now - skidTimer >= SKID_DUR_MS){
        skidCount++;
        lastEvent = "SKID DETECTED – alert!";
        Serial.printf("[ALERT] Skid: ay=%.2fg gx=%.0f°/s\n", ay, gx);

        if(!simMode){
          nrfSendCoords(lastLat, lastLng, "Skid detected");
        } else {
          nrfSendTest(98, "SIMSKID");
          lastEvent = "SIM SKID confirmed (drill)";
        }
        startSOSAlert();
        inSkid = false;
      }
    } else {
      inSkid = false;
    }
  }

  /* ══════════ Direct-Impact Detector (no freefall precondition) ════
   *  Ref: Sensors 2022 – LF falls produce 4–9g peaks
   */
  if(armed && fallState == FS_IDLE && !inSkid){
    if(aMag > IMPACT_DIRECT_G && (now - lastImpactAlert) > IMPACT_DEBOUNCE){
      lastImpactAlert = now;
      impactCount++;
      lastEvent = "DIRECT IMPACT (" + String(aMag,1) + "g) – alert!";
      Serial.printf("[ALERT] Direct impact: aMag=%.1fg\n", aMag);

      if(!simMode){
        nrfSendCoords(lastLat, lastLng, "Direct impact");
      } else {
        nrfSendTest(97, "SIMIMPACT");
        lastEvent = "SIM IMPACT confirmed (drill)";
      }
      startSOSAlert();
    }
  }

  /* ══════════ Environmental / Structural Instability ══════════════ */
  if(now - lastAnalyze >= ANALYZE_EVERY_MS && bufCount >= 10){
    lastAnalyze = now;

    float tmpMag[BUF_N], tmpRoll[BUF_N], tmpPitch[BUF_N];
    int n = bufCount;
    for(int i=0;i<n;i++){
      int idx = (bufIdx - n + i + BUF_N) % BUF_N;
      tmpMag[i]   = magBuf[idx];
      tmpRoll[i]  = rollBuf[idx];
      tmpPitch[i] = pitchBuf[idx];
    }
    float sMag   = stddev(tmpMag,   n);
    float sRoll  = stddev(tmpRoll,  n);
    float sPitch = stddev(tmpPitch, n);

    bool groundShock = (sMag >= ACC_STD_DANGER) && (sRoll < ROLL_PITCH_STD && sPitch < ROLL_PITCH_STD);
    bool waveMotion  = (sMag >= ACC_STD_DANGER*0.6f) && (sRoll >= ROLL_PITCH_STD || sPitch >= ROLL_PITCH_STD);

    if(armed && !simMode){
      if(groundShock){
        lastEvent = "Structural impact / high drop";
        nrfSendCoords(lastLat, lastLng, "Ground shock");
        startSOSAlert();
      } else if(waveMotion){
        lastEvent = "Unstable wave motion";
        nrfSendCoords(lastLat, lastLng, "Wave motion");
        startSOSAlert();
      }
    }

    if(streamToSerial){
      Serial.printf("A_m=%.3f ay=%.2f  roll=%.1f  pitch=%.1f  fix=%d  armed=%d  fall=%d  sim=%d | %s\n",
                    aMag, ay, roll, pitch, (int)hasFix,
                    (int)armed, (int)fallState, (int)simEvent, lastEvent.c_str());
    }
  }

  /* ══════════ Non-blocking SOS pattern driver ═══════════════════ */
  if(alertActive && armed){
    if(millis() >= sosNextChange){
      sosIdx = (sosIdx+1) % SOS_N;
      bool on = SOS_STEPS[sosIdx].on;
      digitalWrite(ALERT_LED_PIN, on ? HIGH : LOW);
      if(on) buzzerOn(3000); else buzzerOff();
      sosNextChange = millis() + SOS_STEPS[sosIdx].ms;
    }
  } else if(!armed && alertActive){
    stopSOSAlert();
  }
}

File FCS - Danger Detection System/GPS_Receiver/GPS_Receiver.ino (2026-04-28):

/*  GPS_Receiver.ino  –  v2.2
 *  Pro Micro (ATmega32U4) + NRF24L01  →  HID Keyboard
 *
 *  Receives two payload types from the ESP32 transmitter:
 *
 *  1. EMERGENCY payload  "TOKEN,LAT,LNG"
 *     → Opens:  https://danger-monitor-profile.netlify.app/?token=DM-001&loc=LAT,LNG
 *
 *  2. TEST payload       "TEST,NN,<tag>"  (burst test and sim drills)
 *     → Opens:  https://danger-monitor-profile.netlify.app/?nrftest=1&seq=NN&ts=<millis>
 *     The Netlify page shows a "Test Received" notification instead of the emergency profile.
 *     Transmission delay is measured on the transmitter side via RF24 ACK timing;
 *     the seq number allows correlation of results in the dashboard.
 *
 *  Wiring:
 *    NRF24  CE  → pin 9
 *    NRF24  CSN → pin 10
 *    NRF24  MOSI→ MOSI (pin 16 on Pro Micro)
 *    NRF24  MISO→ MISO (pin 14)
 *    NRF24  SCK → SCK  (pin 15)
 *    NRF24  VCC → 3.3 V  (do NOT use 5 V!)
 *    LED_BUILTIN → blinks on every received packet
 */

#include <SPI.h>
#include <RF24.h>
#include <Keyboard.h>

#define CE_PIN   9
#define CSN_PIN 10

RF24 radio(CE_PIN, CSN_PIN);

const uint64_t NRF_ADDRESS  = 0xE8E8F0F01LL;
const uint8_t  NRF_PAYLOAD  = 32;              // must match transmitter

/* ── Netlify base URLs ─────────────────────────────────────────────── */
const char* NETLIFY_BASE      = "https://danger-monitor-profile.netlify.app/?token=";
const char* NETLIFY_TEST_BASE = "https://danger-monitor-profile.netlify.app/?nrftest=1&seq=";

#define LED_PIN  LED_BUILTIN

/* ── Debounce timer ─────────────────────────────────────────────────  */
uint32_t lastTrigger = 0;
const uint32_t DEBOUNCE_MS = 1500;   // ignore re-transmissions within this window

/* ─────────────────────────────────────────────────────────────────── */
void setup(){
  Serial.begin(115200);
  pinMode(LED_PIN, OUTPUT);
  digitalWrite(LED_PIN, LOW);

  if(!radio.begin()){
    Serial.println("[NRF] Init FAILED – check wiring!");
    while(true){
      digitalWrite(LED_PIN, HIGH); delay(100);
      digitalWrite(LED_PIN, LOW);  delay(100);
    }
  }

  radio.setPayloadSize(NRF_PAYLOAD);
  radio.openReadingPipe(0, NRF_ADDRESS);
  radio.setPALevel(RF24_PA_HIGH);
  radio.startListening();

  Keyboard.begin();
  Serial.println("[NRF] Receiver v2.2 ready.");
}

/* ─────────────────────────────────────────────────────────────────── */
void loop(){
  if(!radio.available()) return;

  char payload[NRF_PAYLOAD + 1] = {0};
  radio.read(payload, NRF_PAYLOAD);
  String raw = String(payload);
  raw.trim();

  uint32_t now = millis();

  /* ── LED blink on every reception ── */
  digitalWrite(LED_PIN, HIGH); delay(60); digitalWrite(LED_PIN, LOW);

  /* ── Detect payload type ─────────────────────────────────────── */
  if(raw.startsWith("TEST,")){
    /* TEST payload from burst test or simulation drill.
     * Format: "TEST,NN,tag"
     * NN  = 2-digit sequence number (01–20 for burst, 97-99 for sim drills)
     */
    Serial.print("[NRF] TEST payload: "); Serial.println(raw);

    // Extract sequence number (chars 5-6)
    String seq = "";
    int firstComma  = raw.indexOf(',');
    int secondComma = raw.indexOf(',', firstComma + 1);
    if(firstComma >= 0 && secondComma > firstComma){
      seq = raw.substring(firstComma + 1, secondComma);
    } else if(firstComma >= 0){
      seq = raw.substring(firstComma + 1);
    }

    if((now - lastTrigger) < DEBOUNCE_MS){
      Serial.println("[NRF] TEST debounced – skipped");
      return;
    }
    lastTrigger = now;

    /* Type the test notification URL */
    Keyboard.press(KEY_LEFT_CTRL);
    Keyboard.press('l');
    Keyboard.releaseAll();
    delay(220);

    Keyboard.press(KEY_LEFT_CTRL);
    Keyboard.press('a');
    Keyboard.releaseAll();
    delay(70);

    Keyboard.print(NETLIFY_TEST_BASE);   // "...?nrftest=1&seq="
    Keyboard.print(seq);                  // e.g. "05"
    Keyboard.print("&ts=");
    Keyboard.print(String(now));          // receiver-side millis (informational)
    delay(70);
    Keyboard.write(KEY_RETURN);

    Serial.print("[HID] Test notification: seq="); Serial.println(seq);

  } else {
    /* EMERGENCY payload: "TOKEN,LAT,LNG" */
    int firstComma  = raw.indexOf(',');
    int secondComma = raw.indexOf(',', firstComma + 1);

    if(firstComma < 0 || secondComma < 0){
      Serial.print("[NRF] Malformed payload ignored: "); Serial.println(raw);
      return;
    }

    String token  = raw.substring(0, firstComma);
    String coords = raw.substring(firstComma + 1);

    Serial.print("[NRF] EMERGENCY | Token: "); Serial.print(token);
    Serial.print("  Coords: ");               Serial.println(coords);

    if((now - lastTrigger) < DEBOUNCE_MS){
      Serial.println("[NRF] EMERGENCY debounced – skipped");
      return;
    }
    lastTrigger = now;

    /* HID sequence → open emergency profile */
    Keyboard.press(KEY_LEFT_CTRL);
    Keyboard.press('l');
    Keyboard.releaseAll();
    delay(250);

    Keyboard.press(KEY_LEFT_CTRL);
    Keyboard.press('a');
    Keyboard.releaseAll();
    delay(80);

    Keyboard.print(NETLIFY_BASE);    // ".../?token="
    Keyboard.print(token);           // e.g. "DM-001"
    Keyboard.print("&loc=");
    Keyboard.print(coords);          // e.g. "14.599512,120.984222"
    delay(80);
    Keyboard.write(KEY_RETURN);

    Serial.print("[HID] Emergency URL → token="); Serial.print(token);
    Serial.print("  loc="); Serial.println(coords);
  }
}

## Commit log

2026-04-03 Initial commit - Danger Monitor System
    [LIfeVest_Receiver.kicad_pcb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]
2026-04-03 Revise README for SHM System full documentation
    Updated the README to provide comprehensive documentation for the Structural Health Monitoring System, including system overview, architecture, program flow, and detailed descriptions of tasks and fu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
2026-04-03 Initial commit V2
    [Danger Monitor System_Receiver.kicad_pcb, Danger Monitor System_Receiver.kicad_sch, Danger Monitor System_Transmitter.kicad_pcb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]
2026-04-03 Bug Fixed sa NRF
    [GPS_Danger_Monitor.ino, GPS_Receiver.ino]
2026-04-28 Update print statement from 'Hello' to 'Goodbye'
